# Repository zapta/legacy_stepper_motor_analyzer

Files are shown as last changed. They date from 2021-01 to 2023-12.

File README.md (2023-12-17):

# Legacy Stepper Motor Analyzer

<span style="color:red"><b>
NOTE: This is the legacy STM32 based design which was  replaced by the single board, Raspberry Pi Pico design at https://github.com/zapta/simple_stepper_motor_analyzer.</b></span>

&nbsp;

https://github.com/zapta/legacy_stepper_motor_analyzer

&nbsp;

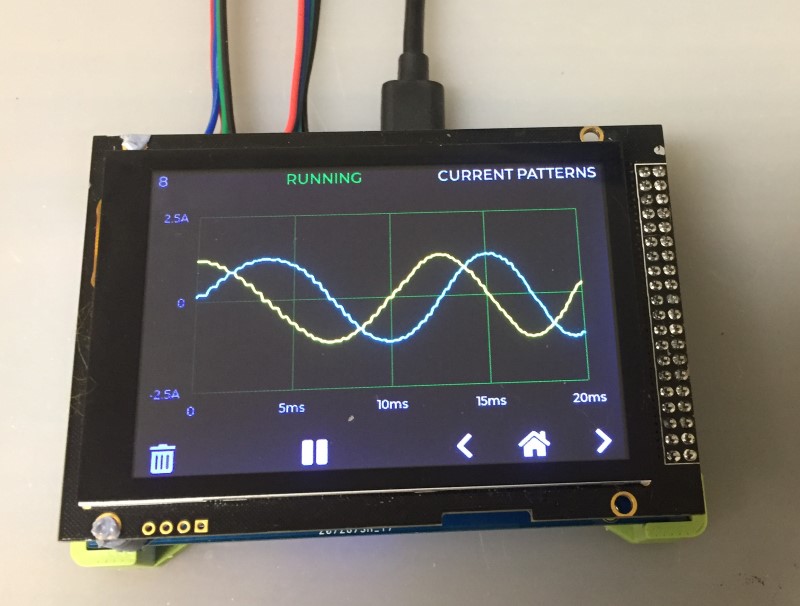
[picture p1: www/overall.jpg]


&nbsp;

## Demonstration

Michael from the Teaching Tech youtube channel made [a great video explaining how stepper motors work](https://youtu.be/4iII25DGIdA) and used the Simple Stepper Motor Analyzer for some of the demonstrations. 

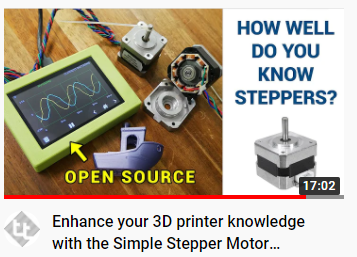
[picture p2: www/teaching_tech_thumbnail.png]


&nbsp;

## Highlights
* Low cost and minimalist DYI hardware design.
* Standalone. Doesn't require a computer to operate.
* Analyzes the stepper motor signals in the actual system (e.g. a 3D printer).
* Galvanically isolated current sensors. Does not interfere with the operating equipment, even when its turned off.
* Easy to connect using a pair 4 wire pass through connectors.
* Intuitive user interface with color display and a capacitive touch.
* Microstepping resolution of 1% of a full step.
* Provides momentary readings, signal patterns, and statistical measurements.
* Hardware and software are open sourced with a generous license.
* Based on free tools (Kicad, platformio, LVGL, STM32Duino).
* Can be easily customized (new featured, cost reduction, data link to a computer, etc).
* Powered 5VDC, 200ma via a USB-C connector.

## Overview
Diagnosing the operation of stepper motor in 3D printers and CNC machines used to require stepper motor analyzers that costs thousands of dollar. Not anymore! The Simple Stepper Analyzer ('Analyzer' in short) brings these capabilities to every maker for a tiny fraction of the price and with a minimalist DIY electronic design that leaves the heavy lifting to the firmware.

The Analyzer is self contained, has two 4-wires pass-through connectors connecting the stepper motor, is powered from a common 5V charger with a micro USB cable, provides a simple to use graphical user interface with a 3.5" color touch screen, and provides a plethora of stepper motor measurements.

The Analyzer is provided to the community as a public domain reference design that can be built and used as is, or be customized with additional features or for a lower cost as desired. The hardware and firmware come with a liberal open source license (CC0) that allows commercial usages and doesn't require code source code sharing.

---
## Disclaimer
THE DESIGN IS PROVIDED "AS IS", WITHOUT WARRANTY OF ANY KIND, EXPRESS OR IMPLIED, INCLUDING BUT NOT LIMITED TO THE WARRANTIES OF MERCHANTABILITY, FITNESS FOR A PARTICULAR PURPOSE AND NONINFRINGEMENT. IN NO EVENT SHALL THE AUTHORS OR COPYRIGHT HOLDERS BE LIABLE FOR ANY CLAIM, DAMAGES OR OTHER LIABILITY, WHETHER IN AN ACTION OF CONTRACT, TORT OR OTHERWISE, ARISING FROM, OUT OF OR IN CONNECTION WITH THE DESIGN OR THE USE OR OTHER DEALINGS IN THE DESIGN.

---

## Alternative construction option (enclosed case)
**NOTE:** This pages outlines the open base construction options which is easier and straight forward. For a more involved and potentially more satisfying construction option, which is also featured in the Teaching Tech youtube video, see https://github.com/zapta/legacy_stepper_motor_analyzer/blob/master/case_option.md

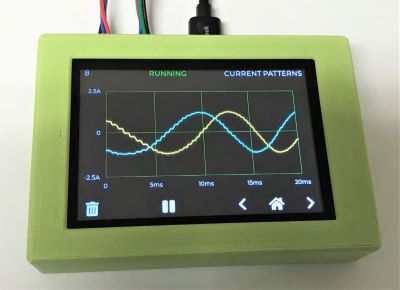
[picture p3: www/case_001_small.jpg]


---
## How does it work?
The principle of operation is very simple, and so is the hardware design. The stepper motor is connected via 4 wire pass-though connectors that allow the Analyzer to monitor the current through the stepper's coils. The Analyzer's user low impedance current sensors that are galvanically isolated such does not interfere with the operation of the 3D printer or other equipment it monitors. The Analyzer measures the coils currents 100k times a second and uses firmware that analyzes the data, extracts the desired measurements, and present them on the screen. For example, this is how an analysis of the distribution of distance by speed distribution looks like:

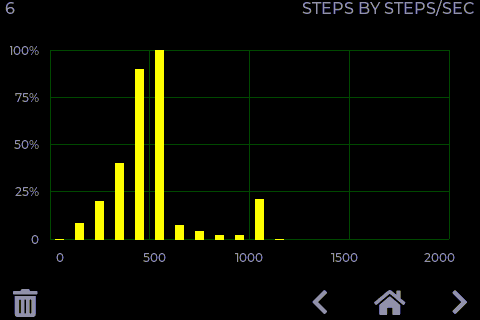
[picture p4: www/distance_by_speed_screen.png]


---
## Operation is simple and intuitive

1. Turn off power to the equipment (e.g. 3D printer).
2. Disconnect the 4 wires of the stepper motor and connect them through the Analyzer two pass through connectors.
3. Power the analyzer using a 5V charger and a micro USB cable.
4. Turn on the equipment and get the stepper going.
5. Use the Analyzer's screen to view the measurements you want.

**NOTE:** The two pass-through connectors of the Analyzer are symmetric and  each can act as an input or output. 

**CAUTION:** Always connect and disconnect stepper motors when their controller is not energized, to reduce the risk of damage to the controller due to high voltage spikes. The analyser itself is not subject to that risk since its uses galvanically isolated current sensors.

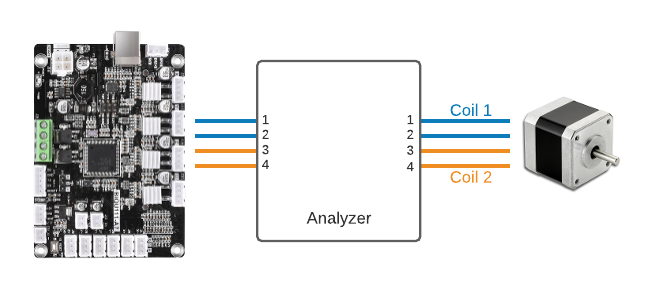
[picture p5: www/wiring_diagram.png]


**NOTE:** The only requirement for proper wiring is that the two wires of one coil should go through pins pair 1,2 and the two wires of the other coil should go through pin pair 3,4. The Analyzer doesn't care about the +/- polarity of the wires in each pair, nor does it care which of the two pass-through connectors is on the controller side and which one is on the stepper side.

**TRIVIA:**: The pin out and the connector type of the Analyzer follows the Duet3D conventions, except that is uses right angle connector to save space.

---
## The Home Page
The Home page is first page shown when the Analyzer is powered on. It provides summary information as well as access to the Settings page.

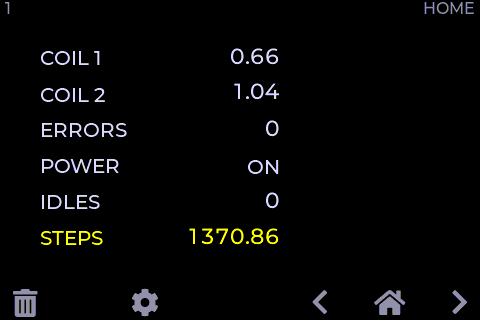
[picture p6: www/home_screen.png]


&nbsp;

#### Page Data

Field | Description
:------------ | :-------------
 COIL&nbsp;1 | Momentary coil 1 current in Amps.
 COIL&nbsp;2 | Momentary coil 2 current in Amps.
 ERRORS | The number of phase errors detected so far. Phase errors happens when the current patterns are so distorted that a forward/backward movement cannot be determined.
 POWER | Indicates if the stepper motor is currently energized. This is determined by the sum of currents in they two coils.
 IDLES | The number of times that stepper motor change status from energized to non energized.
 STEPS | The distance the stepper moved so far. Each full step forward increments this value by one and each full step backward decrements it by one. When the stepper motor is energized, the display also shows fractional steps in resolution of 1/100th of a full step.

HINT: The fractional step value cannot be reset because it is derived from the momentary currents in the two coils. Only the stepper motor driver can reset the fraction by positioning the stepper motor on an exact full step.

HINT: To swap forward/backward directions of the Analyzer use the Settings page. This does not affect the stepper motor itself.

&nbsp;
#### Page Actions

Action | Description
:------------: | :-------------
 | Clear all data.
 | Open the Settings page.

&nbsp;

---

## The Settings Page

This is a special page that is accessible from the Home page and allows to calibrate the Analyzer. The settings are stored in a non volatile memory and are preserved when the Analyzer is turned off.

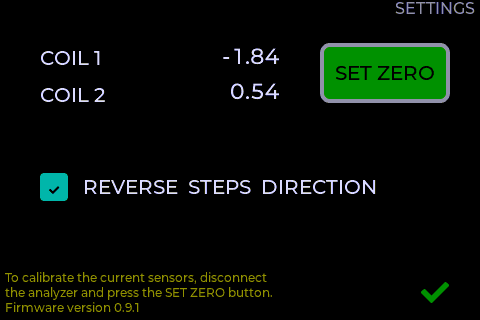
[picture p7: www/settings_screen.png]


&nbsp;
#### Page Data

Data | Description
:------------: | :-------------
COIL&nbsp;1 | The momentary current of stepper coil 1 in Amp units. Should be zero, or very close to zero, when the stepper motor is disconnected.
COIL&nbsp;2 | The momentary current of stepper coil 2 in Amp units. Should be zero, or very close to zero, when the stepper motor is disconnected.

&nbsp;
#### Page Actions

Action | Description
:------------: | :-------------
SET ZERO | Used to calibrate the zero reading of the current sensors. To do so, Disconnect the stepper motor and press this button.
REVERSE STEPS DIRECTION | Changes the forward/backward step directions of the Analyzer. Does not affect the stepper motor itself. Having the correct direction is important for measurements such as the Retraction analysis.
 | Press exist the Settings page.

&nbsp;

---

## The Speed Dial Page

This page measure the stepper speed in units of full steps per second. 

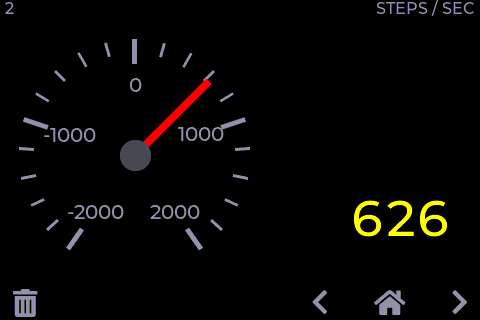
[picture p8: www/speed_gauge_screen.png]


&nbsp;
#### Page Data

Data | Description
:------------ | :-------------
Speed&nbsp;Dial | The speed dial shows the momentary stepper speed in full steps per second units. Forward speed is on the right side and backward speed is on the left.
Speed&nbsp;Value | This field shows the speed in a numeric form. IT is updated less frequently than the dial to allow easy reading.

&nbsp;
**HINT:** The Settings page allows to swap the forward/backward directions.

&nbsp;
#### Page Actions

Action | Description
:------------: | :-------------
 | Clears all data.
Tap the dial |Toggles the dial's speed range.

&nbsp;

---

## The Distance Graph Page

This page shows scrolling graph with the total number of full steps vs. time.

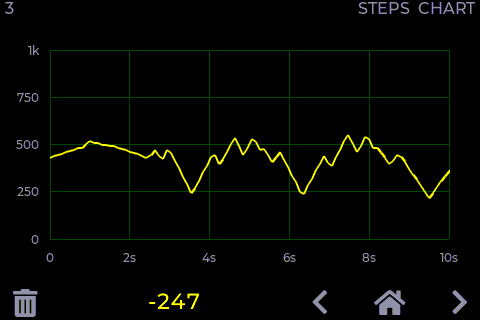
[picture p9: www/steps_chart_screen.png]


&nbsp;

#### Page Data

Data | Description
:------------ | :-------------
Distance&nbsp;Graph | This graph shows how the distance, in units of full steps, changes over time.
Distance&nbsp;value | The numeric value of the distance in full steps.  This fields is identical to the STEPS field in the Home page.

&nbsp;

#### Page Actions

Action | Description
:------------: | :-------------
 | Clears all data.
Tap the graph | Toggles the range of the vertical axis.

&nbsp;

---

#### The Retraction Graph Page

This page is useful to analyze the retraction in of 3D printer extruder.

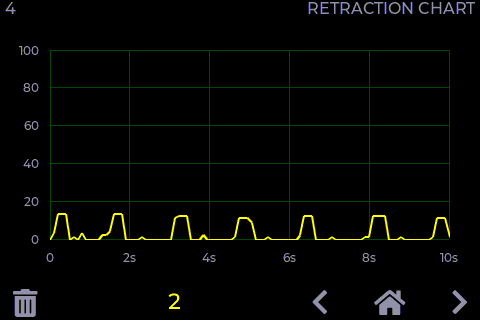
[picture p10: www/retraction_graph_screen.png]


&nbsp;
**TRIVIA:** The graph above was taken while testing a direct extruder printer with [Thing #909901](https://www.thingiverse.com/thing:909901).
&nbsp;
#### Page Data

Data | Description
:------------ | :-------------
Retraction&nbsp;Graph | This graphs tracks the retraction of 3D extruder full step units.  Retraction is defined as the filament length that was inside the extruder and is now retracted outside of the extruder. 
Retraction value |  This field shows the current retraction level in a numeric form.

&nbsp;
#### Page Actions

Action | Description
:------------: | :-------------
 | Clear all data.
Tap the graph | Changes the range of the vertical axis.

&nbsp;

---

## The Time by Speed Page

This page shows an histogram with the distributing of time by stepper speed. That is how much time was spent in each speed range. The values are normalized such that the longest bar is always at 100%.

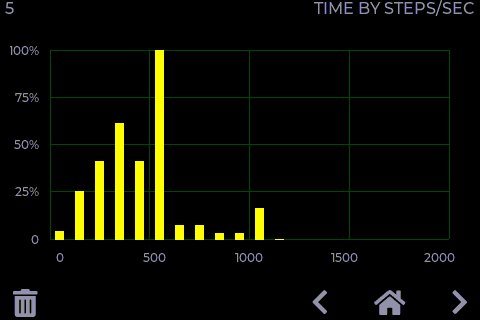
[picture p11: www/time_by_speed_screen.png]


&nbsp;
#### Page Data

Data | Description
:------------ | :-------------
Time&nbsp;Histogram | The horizontal axis indicates speed in full steps per second units. The height of each bar indicate the time of all steps in that speed range, with the length of the longest bar normalized to 100%.

&nbsp;
#### Page Actions

Action | Description
:------------: | :-------------
 | Clear all data.

&nbsp;

---

## The Distance by Speed Page

This page shows an histogram with the the distribution of distance by stepper speed.



&nbsp;
#### Page Data

Data | Description
:------------ | :-------------
Distance&nbsp;Histogram |  The horizontal axis indicates speed in full steps per second units. The height of each bar indicate the distance or number of steps in that speed range, with the length of the longest bar normalized to 100%.

&nbsp;
#### Page Actions

Action | Description
:------------: | :-------------
 | Clear all data.

&nbsp;

---

## The Current by Speed Page

This page measures the ability of the stepper motor's controller to maintain peak current at high speeds.

The screenshot below shows a healthy system where the peak current is virtually flat across the speed range.

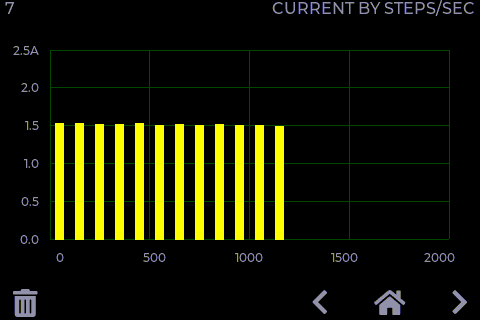
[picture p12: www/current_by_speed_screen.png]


The screenshot below shows a system that is not capable to maintain peak current and starves the stepper motor at high speeds, resulting in poor torque and possible skipped steps.

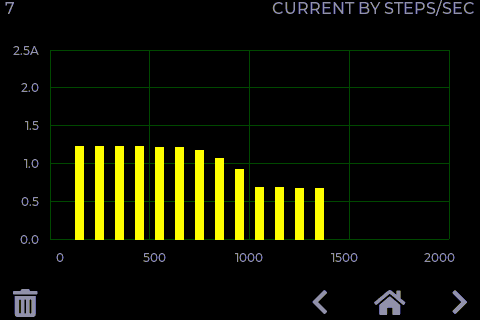
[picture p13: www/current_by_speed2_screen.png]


&nbsp;
#### Page Data

Data | Description
:------------ | :-------------
Peak&nbsp;Current&nbsp;Histogram | The horizontal axis indicates speed in full steps per second units. The height of each bar indicates the average peak current in Amps of  steps that speed range. 

&nbsp;
#### Page Actions

Action | Description
:------------: | :-------------
 | Clear all data.

&nbsp;

---

## Coil Current Patterns Page

This page shows the current patterns in the two stepper coils.

The screenshot below shows a healthy system where the signals are nice and clean and reaches the target peak current.

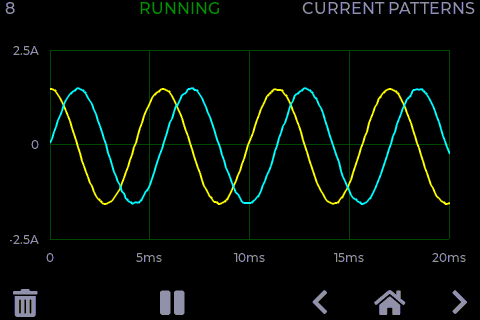
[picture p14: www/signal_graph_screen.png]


&nbsp;

The screenshot below is from a poor system where high speed results in distorted and insufficient current, resulting in loss of torque and a potential for skipped steps.

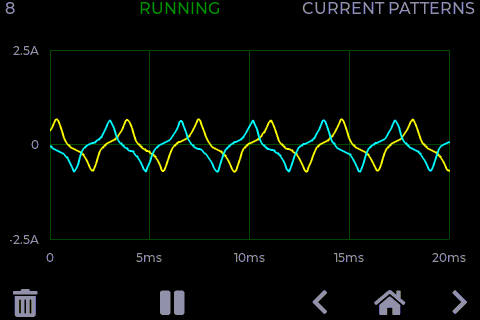
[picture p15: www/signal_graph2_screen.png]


&nbsp;

**GENERAL INFORMATION:** Each cycle of the stepper current pattern represent 4 full steps. The centers of those steps are at on the four vertical dotted lines where the currents of the two coils are identical, in the same or in  opposite polarities. The transitions between the steps are on the 4 vertical solid lines where one of the coils is at zero current. This cycle of 4 full steps is sometimes referred to as a single 'electric rotation'. The analyzer computes the exact phase on this cycle using the standard trigonometric function atan2(current1, current2) which can also be calculated manually from the current readings in the Home page.

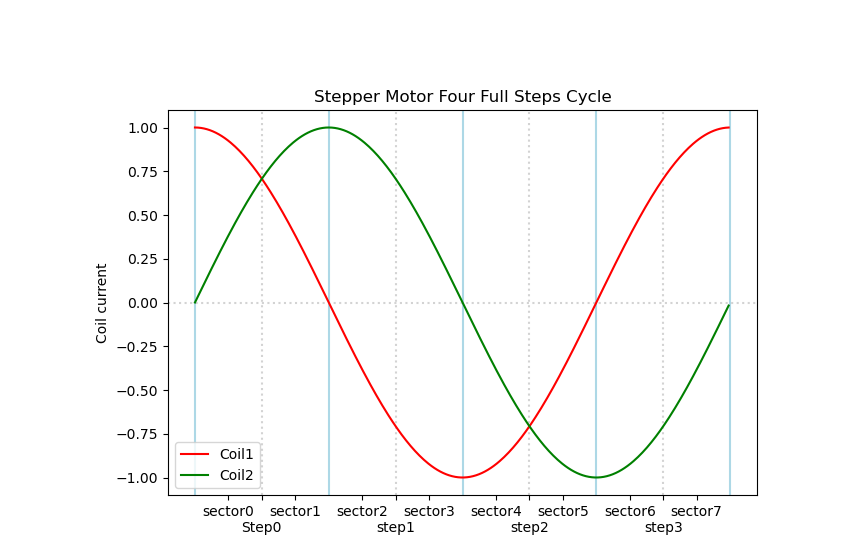
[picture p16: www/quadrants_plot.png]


&nbsp;

#### Page Data

Data | Description
:------------ | :-------------
Current&nbsp;graph | The horizontal axis indicates time in milliseconds. The vertical axis indicate coil current level in Amps. The two graphs show the current patterns of the respective stepper coils.

**NOTE:** The graph is updated only when sufficient stepper motor movement is detected.

&nbsp;
#### Page Actions

Action | Description
:------------: | :-------------
 | Clear all data.
 | When running, pauses the display updates.
 | When paused, resume the display updates.
Tap the graph | This toggles the range of the horizontal axis.

&nbsp;

---

## Coil Current Phase Page

This page draws the current patterns of the two coils as a [Lissajous curve](https://en.wikipedia.org/wiki/Lissajous_curve) which allows to examine visually distortions such as non sinusoidal current, phase distortion, and reduced amplitude.

In an ideal system, the graph is a perfect smooth circle, that doesn't change its size when the stepper's speed changes. Patterns that significantly diverge from that indicates a sub optimal configuration and operation.

Following picture shows a pattern from a well functioning system. The graph is round, reasonable smooth, and has sufficient size which indicates good current drive. 

The horizontal axis indicates the coil 1 current and the vertical axis indicates coil 2 current. In this example, both span nicely between -2A to +2A.

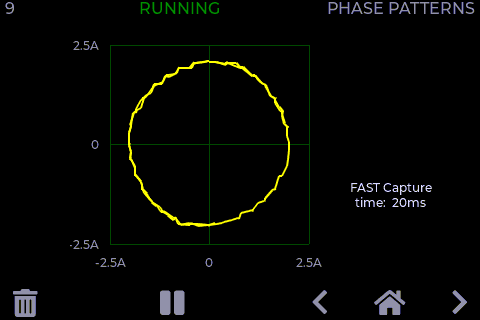
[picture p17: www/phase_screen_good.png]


&nbsp;

The screenshot below is from a poor system where high speed results in distorted and insufficient current, resulting in loss of torque and a potential for skipped steps. The pattern is far from a clean circle and the shape has reduced size.

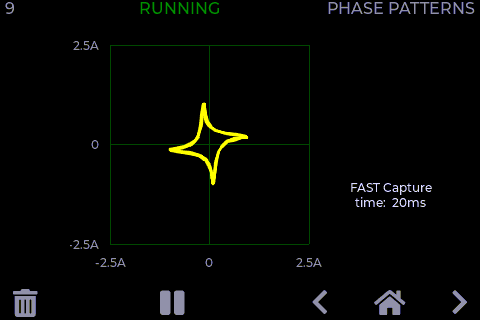
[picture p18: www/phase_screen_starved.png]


&nbsp;

The screenshot below shows a sub optimal operation where a a speed increase of the stepper results in small (less current and torque) and even more distorted curve.

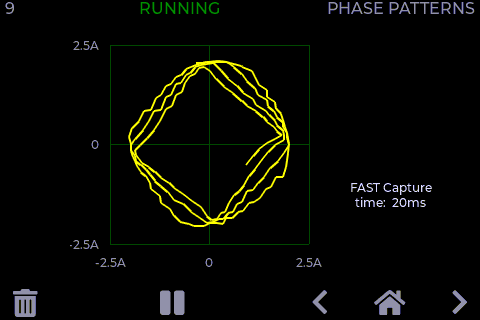
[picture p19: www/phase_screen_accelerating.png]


&nbsp;

The screenshot below shows a well functioning system. The smaller size of the circle compare to the example above indicates that it operates on lower current.

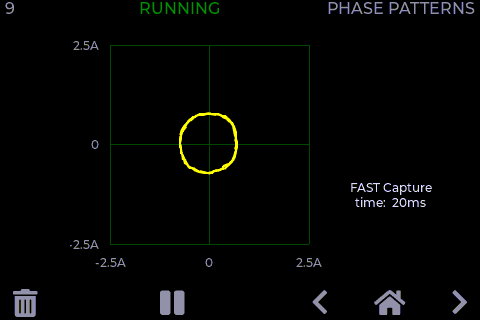
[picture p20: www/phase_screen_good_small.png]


&nbsp;

The screenshot below show an operation of a stepper in full steps mode. The dimension of the pattern indicate good current feed, and the square  shape is the best a full step driver can deliver.

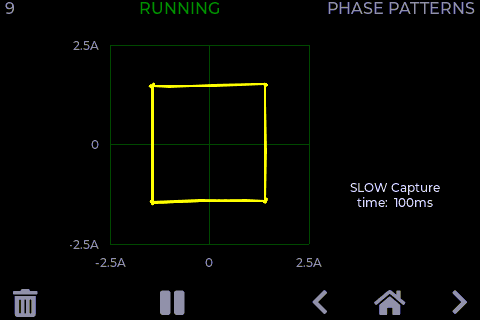
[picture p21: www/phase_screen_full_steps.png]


&nbsp;

The screenshot below show an operation of a stepper in half steps mode. The dimension of the pattern indicate good current feed, and the shape is somewhere between the square shape of full step mode and the round shape of micro stepping interpolation mode.

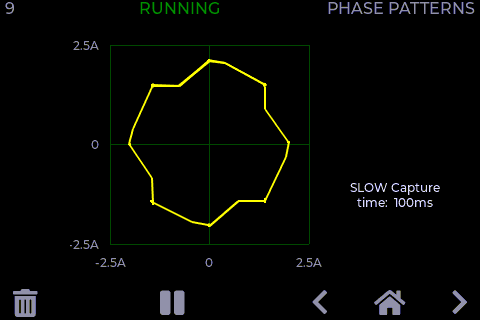
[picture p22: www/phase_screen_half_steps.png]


&nbsp;

#### Page Data

Data | Description
:------------ | :-------------
Lissajous&nbsp;curve | A Lissajous curve drawn from the current pattern of coil 1 (x) and coil2(y). 
Capture speed | Shows the signal capture time. Fast mode works better with fast moving steppers and slow mode works with slow moving steppers. Tap the graph to toggle.

**NOTES** 
* The graph is updated only when sufficient stepper motor movement is detected.
* To view the current pattern that resulted in the current phase pattern, use the navigation button to switch the current patters page, and vice versa.

&nbsp;
#### Page Actions

Action | Description
:------------: | :-------------
 | Clear all data.
 | When running, pauses the display updates.
 | When paused, resume the display updates.
Tap the graph | This toggles the capture time between fast and slow speeds.

&nbsp;

---

## Reference Design Specification

Item | Specification
:------------ | :------------- 
Power consumption | 5V, 175ma.
Power connector | micro USB
MCU | 32bit ARM STM32F401CE @ 84Mhz.
Flashing | USB/DFU or SWD/Stlink V2.
Data link | USB/Serial link available but not used.
Current measurement | +/-2.5A per coil. +/-5A sensors available.
Dimensions | 97 x 66 mm
TFT Resolution | 480 x 320, Color. Landscape mode.
Touch screen | Capacitive
Sensor isolation | See ACS70331 data sheet
Sampling rate | 100Khz per channel.
Sampling resolution | 12bits
Current accuracy | estimated at +/- 1%
Max speed | Software dependent. Currently 2K full steps/sec.
Step resolution | 1/100th of a full step.
Partial steps measurement | Software dependent. Not implemented.
Settings storage | On board EEPROM chip.
GUI framework | LVGL library. R3G3B2 color depth.
Programming language | C++
Programming IDE | Platform.io. Arduino/STM32.
Cad package | Kicad.

&nbsp;

---

## I want to build me one

The electronic schematic, PCB layout, gerber files, and the firmware source files and released binary are all available on this github repository.

[Schematic](./www/stepper_analyzer-sch.pdf)

[BOM](https://github.com/zapta/legacy_stepper_motor_analyzer/blob/master/kicad/BOM.csv)

<span style="color:red"><b>
ERRATA: The current PCB version leaves the RD input on the TFT (pin 26) floating which can  interfere with the operation of the display. One workaround is to patch the board with a resistor to pull the input to +3.3v (but not to +5V!!!). See the errata in the latest schematic for more details.</b></span>

&nbsp;

**Instructions:** Build the PCB, use DFU or SWD protocols to program the released binary into the Blackpill, plugin the TFT screen, power and use. See instructions below on how to flash the firmware release you can find on this github repository.

**NOTE:** These instructions are for the simpler  version which uses an open frame base. For ordering parts and building the enclosed version see https://github.com/zapta/legacy_stepper_motor_analyzer/blob/master/case_option.md .

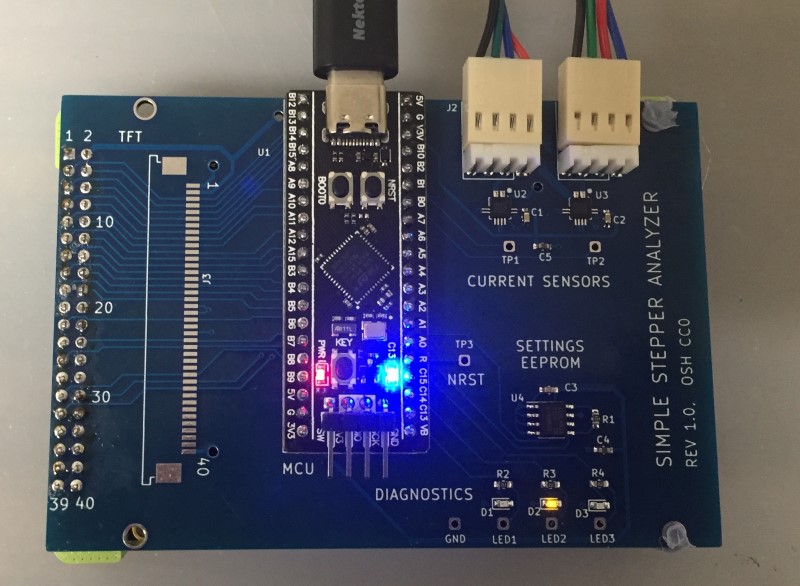
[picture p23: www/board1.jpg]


&nbsp;

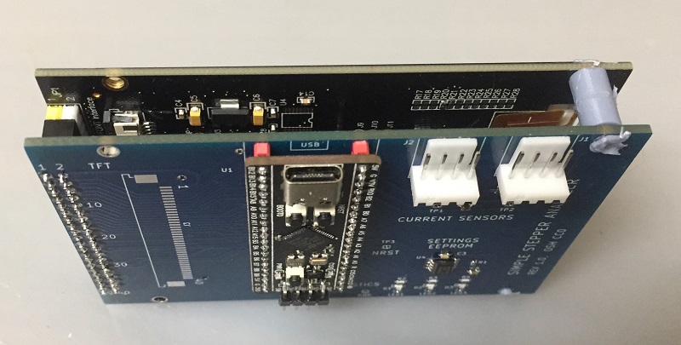
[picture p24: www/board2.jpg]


## Flashing a new firmware
Flashing the Analyzer with firmware can be done in a few ways. For software developers we recommend using StLink V2 and SWD which are well supported by the platformio IDE and enable debugging ans single stepping. A simpler approach that is recommended for end users is to use the builtin DFU protocol of the Analyzer's STM32 processor such as the one we use here. Adafruit has a [good description of the process](https://learn.adafruit.com/adafruit-stm32f405-feather-express/dfu-bootloader-details). The only difference that to enable the DFU bootloader mode connect the analyzer to the computer while its BOOT0 on button on the back is pressed.

**ONLINE LOADER:** We also had good results with Google Chrome browser and this online loader https://devanlai.github.io/webdfu/dfu-util/ . The Analyzer should appear as STM32 BOOTLOADER and should be programmed with the configuration Internal Flash 0x08000000.

## How to modify the firmware?
The source code of the Analyzer is available on this github repository. It is a STM32 C++ Platformio project that uses the Arduino framework. The user interface is based on the LVGL library and the project includes its own port to support TFT/Touch used.  Knowledge of C++ and Platformio is required and is outside the scope of this document.

## Mechanical
We provide here a [3D model of a simple open frame carrier](./3d/base.stl). This design does not requires attaching the analyzer and the TFT board with screws or spacers and guarantees proper separation on the loose end. If you have an interesting design which you would like to share, please post in a model sharing site such as cults3d, thingiverse or grabcad and we will link it here.

This open frame base does not require any spacers between the two boards and was designed 
to prevent them from unintentionally touching each other.

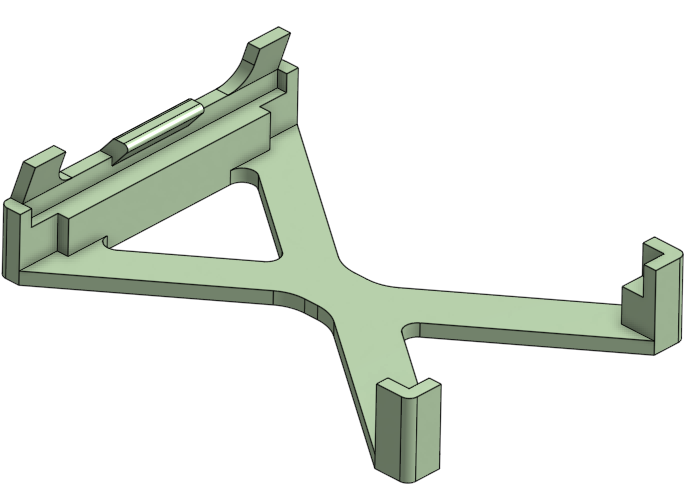
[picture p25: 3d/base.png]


## Ideas for improvements
The Analyzer is provided as a fully functional reference design and changes and the developers encourage improvement/modifications of the hardware and/or firmware are encouraged. This can include new features, new measurements and pages, extending the design to support 2 or 3 steppers at once to track the x/y/z of a 3D printer, reducing the hardware cost using less expensive screen TFT, or even eliminating the screen altogether and using the Analyzer as a dongle tethered to a computer via the existing USB/Serial link.

&nbsp;

---

## FAQ

#### Q: Why not a SPI based TFT?

A: We could not achieve fast enough display refresh rate with SPI so switched to 16 bit parallel data transfers.

#### Q: Can a cheaper TFT/touch be used?
A: Yes, but it may require firmware changes.

#### Q: Can the TFT screen be eliminated?
A: Yes. The Analyzer has a USB/Serial output can a small Analyzer dongle can communicate with a computer program. This will require firmware changes.
 
#### Q: Can I connect the Analyzer to the TFT using a FFC cable?

A: Yes. The PCB was designed for both 0.1" header and 40 pins 1.0mm FFC cable connections.  You will need a short (e.g. 60mm or less) type B ('reversed') FFC cable. Cables longer than let's say 100mm may introduce noises the will interfere with the operation of the display. 

#### Q: Can you add feature X or customization Y?

A: Most likely not. The reference design is provided for the community to change and mix.

#### Q: I want to commercialize or crowd source it, can you help me?

A: Most likely not. The reference design is open source and you will need to find others to help you.

#### Q: Where do I file a bug?

A: Use the github repository.

#### Q: Is it ok to connect/disconnect power to the Analyzer while my 3D printer prints?

A: Of course. The Analyzer is isolated from the stepper wires and should not interfere with the operation of the printer.

#### Q: The Analyzer uses LVGL lib, what is the license of that library?

A: At the time of writing this, the LVGL license is available here https://github.com/lvgl/lvgl/blob/master/LICENCE.txt.  The Analyzer's developers are not affiliated with LVGL.

#### Q: Is the LVGL library included in the Analyzer's repository?

A: It's not needed. LVGL is supported by platform.io so the Analyzer's project is set for platform.io to fetch LVGL automatically.

#### Q: Can I use a STM32F401CE MCU with a 8Mhz crystal.

A: The provided firmware assumes a 25Mhz crystal. For a 8Mhz crystal you will need to change the firmware.

#### Q: I can't find a STM32F401CE/25Mhz blackpill but I can find an STM32F411CE/25Mhz, will this work?

A: Most like it will work with the provided firmware as is (and with no performance benefits), but we do not guarantee it. We may switch the official reference design to the STMF411CE/25Mhz if the STM32F401CE/25Mhz, which is less expensive, will not be available.

#### Q: Can I use a blackpill with different pinout than WeAct ?

A: No, unless if you are willing to change the PCB.

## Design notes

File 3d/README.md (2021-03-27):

3D Models for printing. 

Base is an open frame design that uses a standard 0.1" headers to connect
the display and the Analyzer boards.

Case is a closed design that is more appealing but also more difficult
to build. It uses a type B (reversed) 40 wires 0.1" flex cable to connect
the two boards and M2.5 heat inserts to attache the front and the back 
of the case.

Both designs use the same PCB design and use 16 bit parallel data path to the 
display, but with different 40 wires connectors.

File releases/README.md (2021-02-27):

## Simple Stepper Analyzer Releases
This directory contains the official releases of the Simple Stepper Analyzer which are provided as .bin files that can be flashed to the analyzer.

The binaries can be programmed via the USB connector using the builtin STM32 DFU bootloader. The invoke the DFU mode, connect the analyzer to a computer via a USB cable while holding the BOOT0 button at the back of the analyzer.

Unless specified otherwise, the binaries where compiled for a STM32F401CE MCU
(which typically can also run on a STM32F411CE MCU).

&nbsp;

Binary file | version | Comments
:------------ | :------------- | :---------
[firmware-2021-02-26.bin](./firmware-2021-02-26.bin) |  0.9.13 |  Increased buttons' click area.
[firmware-2021-02-15.bin](./firmware-2021-02-15.bin) |  0.9.12 |  Added phase analysis screen.
[firmware-2021-02-01.bin](./firmware-2021-02-01.bin) |  0.9.11 |  First released version.

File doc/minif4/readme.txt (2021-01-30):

Content from https://github.com/WeActTC/MiniF4-STM32F4x1

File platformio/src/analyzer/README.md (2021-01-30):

The acquisition direction contains the part of the firmware that 
process the ADC samples and extracts the measurements. All that processing
is done by an interrupt routine that process every 1ms 100 pairs of 
ADC samples that are collected in memory by a DMA channel. The pairs of ADC
samples are triggered by a 100khz timer that is set in bye ../hal/tim.cc file.

Before you change any part of the interrupt routine make sure you know
what you are doing.

The file quadrant_plot.png shows how a single stepper motor cycles
is divided into 8 cases and 4 quadrant representing 4 full steps.

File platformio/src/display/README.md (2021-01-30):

This directory contains the port of LVGL to the hardware we use. It includes
an ILI9488 480x320 TFT driver, a capacitive touch screen driver and
the LVGL interfaces to these drivers.

To achieve faster refresh rate we use 16 bits data path to the TFT. These
16 output pins are allocated in PORTA and PORTB and we use lookup table
for a fast update of those pins to output a specific 16 bit value.

To reduce memory consumption we also run LVGL in 8 bit color mode and 
use the lookup tables mentioned above to also do the conversion from
LVGL 8 bit colors to the TFT's 16 bit colors.

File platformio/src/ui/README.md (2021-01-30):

This directory contains the GUI screens. They are switched
by screen-manqager.cpp.

The ui.* files contains simple wrappers and common functionality
for working with LVGL.

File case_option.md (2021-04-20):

# Fully enclosed 3D printed case option

&nbsp;

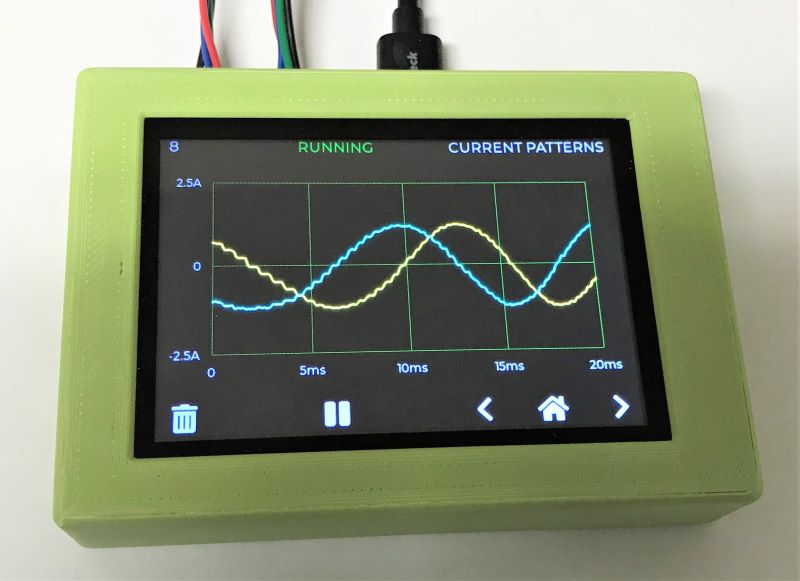
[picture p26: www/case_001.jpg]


&nbsp;

## Summary
This page describes an alternative way to constructs the the Simple Stepper Motor Analyzer that is slightly more involved and arguably more satisfying than the standard option. Instead having the analyzer's board connects to the TFT screen via a 40 pins header and placed on a 3D printed open base, it is attached via a short flex cable (FFC) and is held in a fully enclosed 3D printed case.

## Differences from the the standard open base construction
* This option uses the exact same PCB and electronic components as the standard options.
* Instead of soldering the 2x20 pin 0.1" header on the analyzer's PCB, solder a 40 pin 1.0 FFC surface mount connector.
* Instead of ordering a TFT module with a 40 pin header, order the same TFT module but with the FFC connector option.  (If you already have the TFT module with the 40 pins header option and if you are good with soldering, you can convert it by removing the header and soldering instead a FFC connector).
* Use a short 40 wires (ideal ~30mm, longer such as 60mm should also work), 1.0mm FFC cable to connect the analyzer and TFT boards. You will need a 'type B' or 'reversed' cable type that has the exposed contacts of opposing sides.
* 3D print the parts in the file http://github.com/zapta/simple_stepper_motor_analyzer/blob/master/3d/case.stl
* Set the temperature of your solder iron close to the printing temperature of the case and use it to embed four M2.5 x 3.5mm OD x 3mm length brass threaded inserts.
* Use four M2.5 16mm socket head screw to attach everything together, the four spaces fit between the TFT and the analyzer's PCB.

**NOTE:** The OnShape source file of the case is at 
https://cad.onshape.com/documents/146b8b994145177887407b23/v/f2052a33bf7ac8993e3d7406/e/b6453eca2ba530476c30538a

&nbsp;

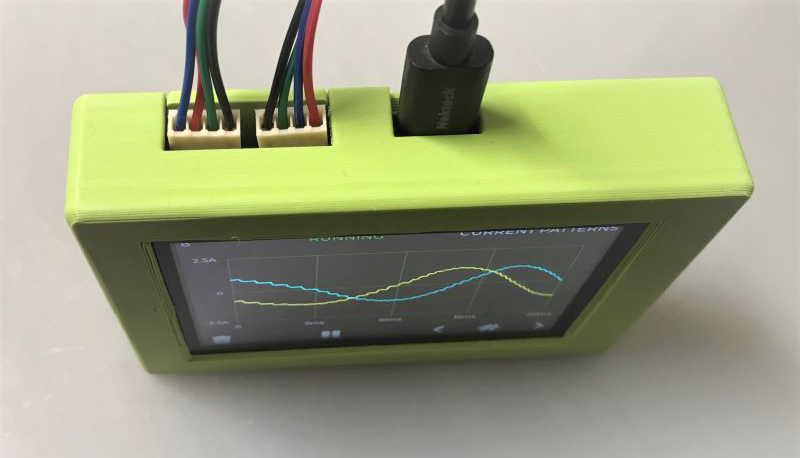
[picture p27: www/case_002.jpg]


&nbsp;

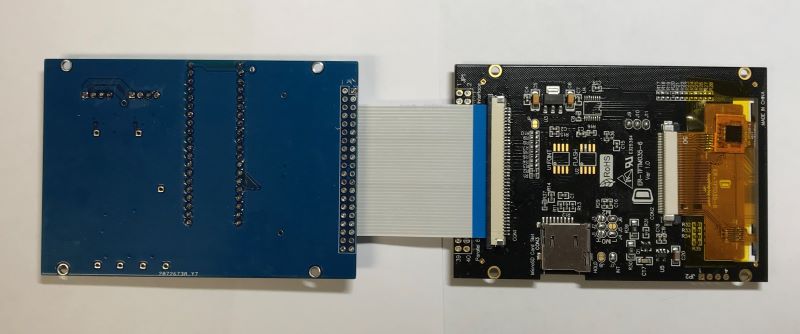
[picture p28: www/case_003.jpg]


&nbsp;

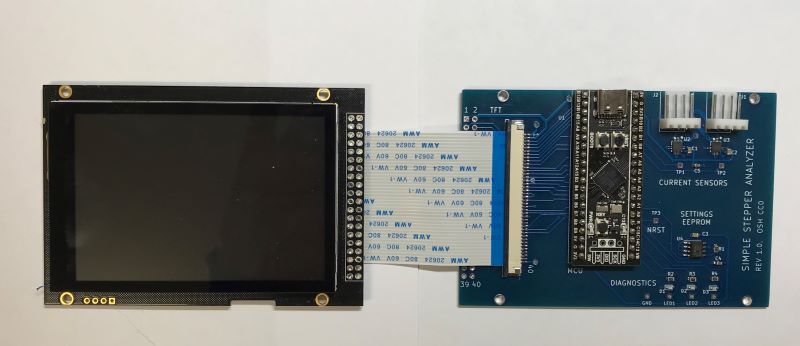
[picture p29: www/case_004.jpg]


&nbsp;

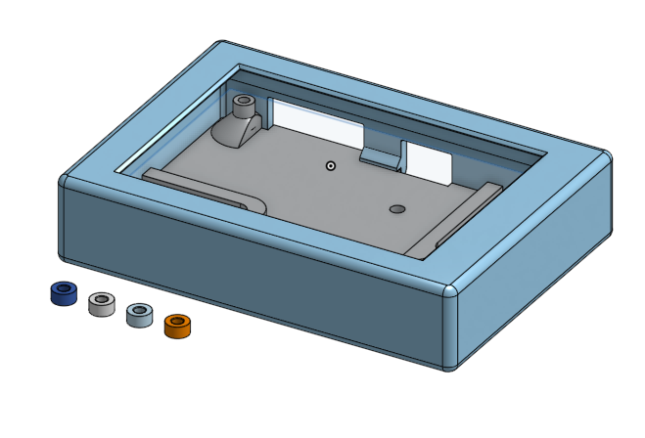
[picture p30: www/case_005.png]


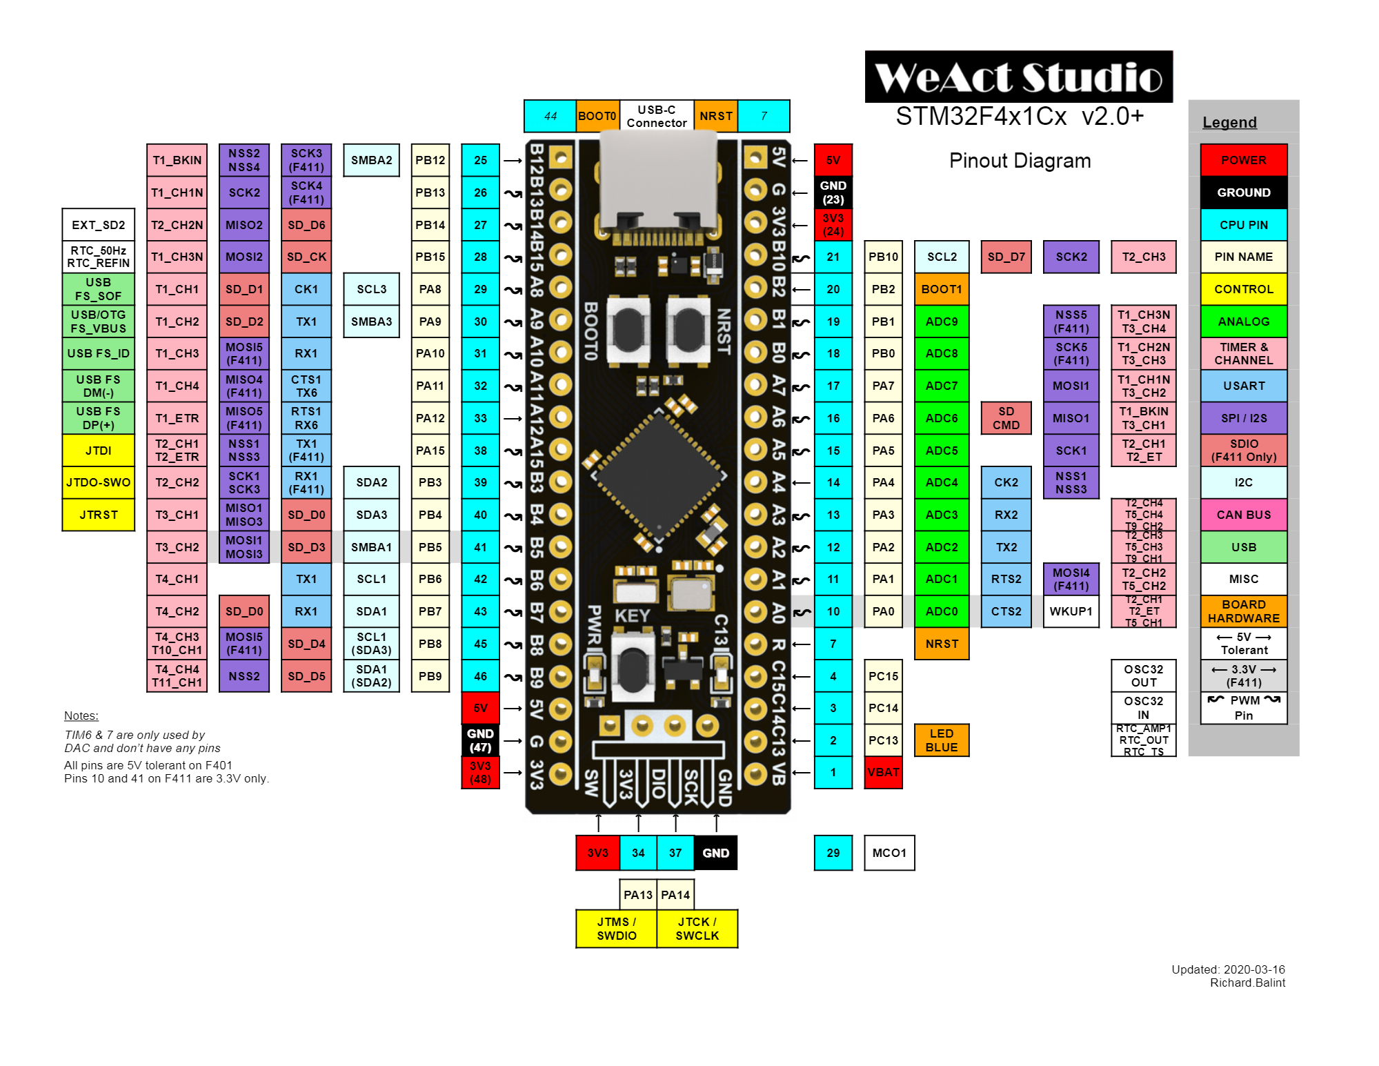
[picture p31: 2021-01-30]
doc/minif4/pinout.png

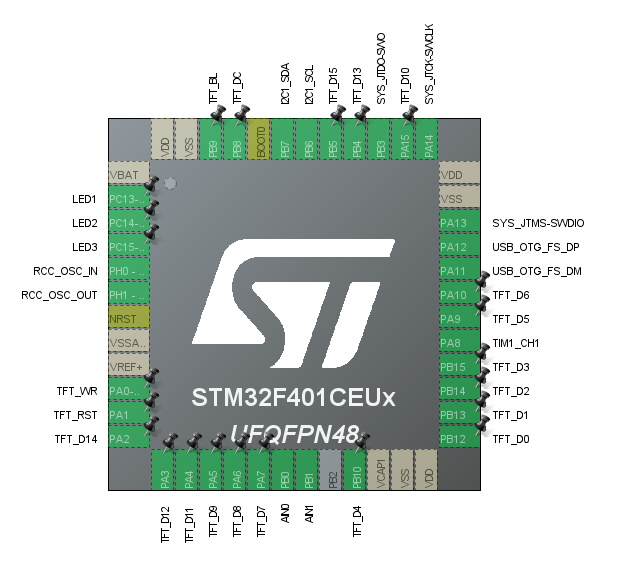
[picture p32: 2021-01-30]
doc/stm32_config/pinout.png

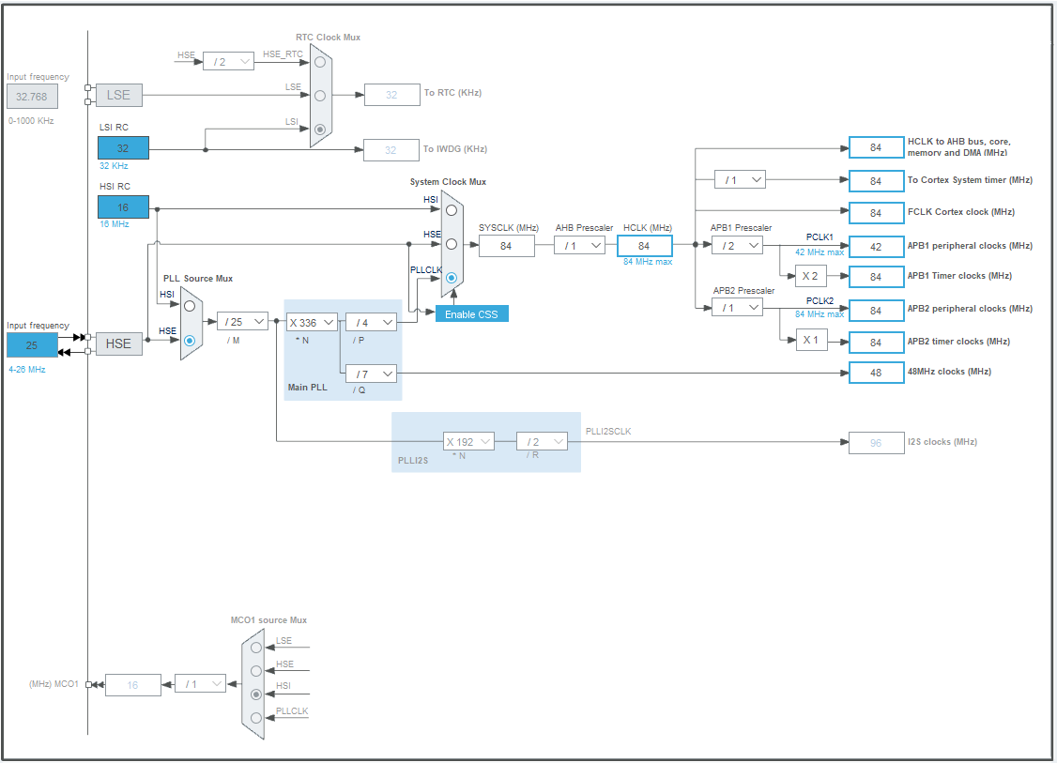
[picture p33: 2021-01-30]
doc/stm32_config/clock.png

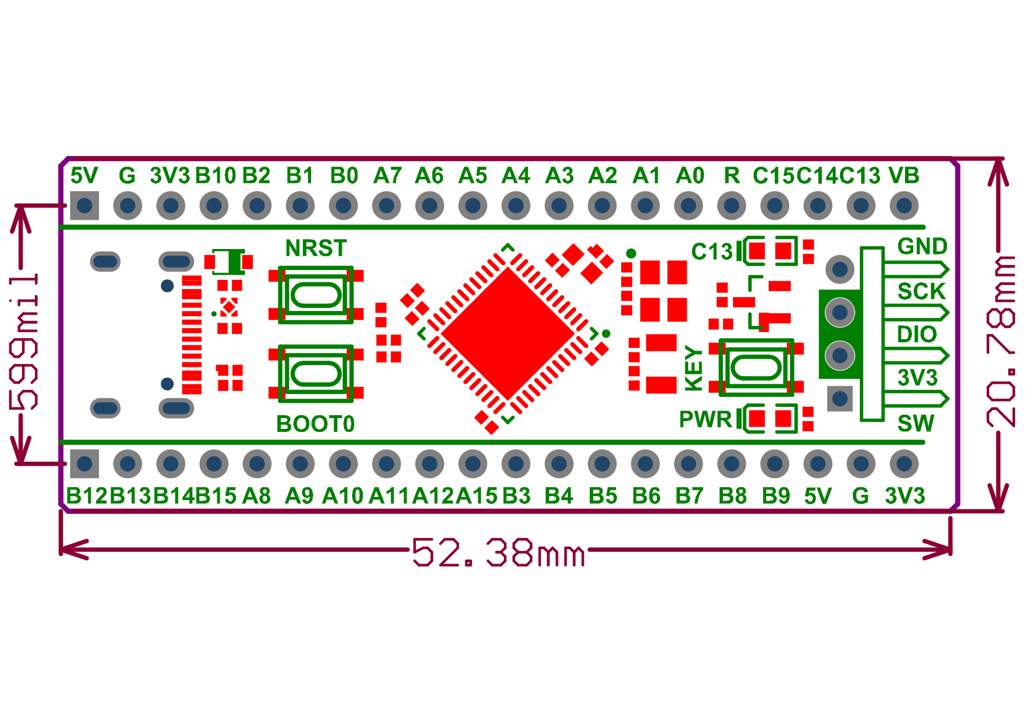
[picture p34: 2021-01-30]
doc/minif4/outline.png

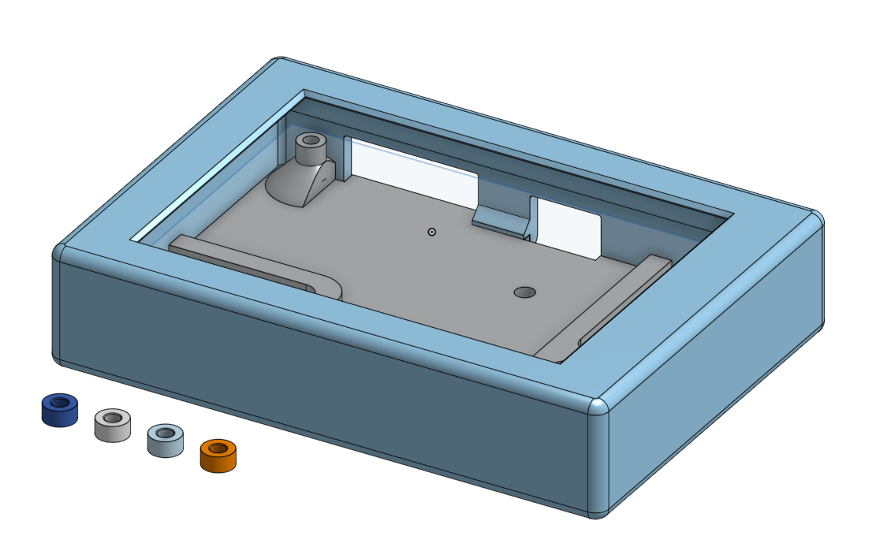
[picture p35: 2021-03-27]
3d/case.png

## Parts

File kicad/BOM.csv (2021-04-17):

Quantity | Ref | Value | Status | Description | Source | Comments
3 | C1, C2, C3 | 100nf | Required | Ceramic capacitor 100nf, at least 10V, SMD 0603 | Digikey 311-1369-1-ND | Generic component, available from other sources.
2 | C4, C5 | 10uf | Requires | Ceramic capacitor 10uf, at least 10V, SMD 0603 | Digikey311-1817-1-ND | Generic component, available from other sources.
1 | R1 | 10k | Required | Chip resistor 10k, SMD 0603 | Digikey 13-AC0603FR-0711KLCT-ND | Generic component, available from other sources.
2 | J1, J2 | 4 pins right angle connector | Required | KF2510 male connector right angle 0.1” pitch pin header | https://www.aliexpress.com/item/4000587555738.html | Generic component, available from other sources.
1 | J4 | 2x20 0.1” female header. | Required | Connector_PinSocket_2.54mm:PinSocket_2x20_P2.54mm_Vertical | https://www.aliexpress.com/item/32747224548.html | Generic component, available from other sources.
1 | U1 | WeAct STM32F4x1CE blackpill module. | Required | WeAct blackpill STM32F401CE 25Mhz or STM32F411CE. Comes with 2x20 pin headers to solder the blackpill to the analyzer’s PCB. | https://www.aliexpress.com/item/1005001456186625.html | Some clones of WeAct modules are available. Make sure to have the same pinout and legit MCU. STM32401CC wouldn’t work, also, make sure it has 25Mhz crystal (vs 8Mhz).
2 | U2, U3 | ACS70331EESATR-2P5B3 | Required | Alegro current sensor, bidirectional, +/-2.5A. | Digikey 620-1889-1-ND
1 | U4 | AT24C02D-SSHM-T | Required | I2C EEPROM 256x8 | Digikey AT24C02D-SSHM-TCT-ND | Clones are available on Aliexpress. We didn’t test them but should work as well.
1 |  | Analyzer PCB Rev 1.0 | Required | Gerber files are available the github repository. 96.7 x 66.4mm two layers. | JLCPCB, Pcbway, your prefer PCB vendor or shop at https://pcbshopper.com/
1 |  | BuyDisplay 3.5” TFT with touch display | Required | ER-TFTM035-6, Pin Header Connection-8080 16-bit Parallel, 5.0V, Capacitive Touch Panel, No font chip. | https://www.buydisplay.com/lcd-3-5-inch-320x480-tft-display-module-optl-touch-screen-w-breakout-board | Make sure to select the exact options listed in the Description column. See example at https://github.com/zapta/simple_stepper_motor_analyzer/blob/master/www/tft_order_options.png
3 | D1, D2, D3 | LED 0603. | Optional, for firmware development only. | LED SMD 0603, colors of your choice. | https://www.aliexpress.com/item/32888575577.html | Generic component, available from other sources.
3 | R2,R3, R4 | 3k3 | Optional, for firmware development only. | Chip resistor 3.3k, SMD 0603 | Digikey YAG3354CT-ND | Generic component, available from other sources.
1 |  | STLINK V2 | Optional, for firmware development only. | Hardware debugger for STM32 MCUs. | Digikey 497-10484-ND | Inexpensive USB dongle clones are available from Aliexpress. We expect them to work but didn’t test them.

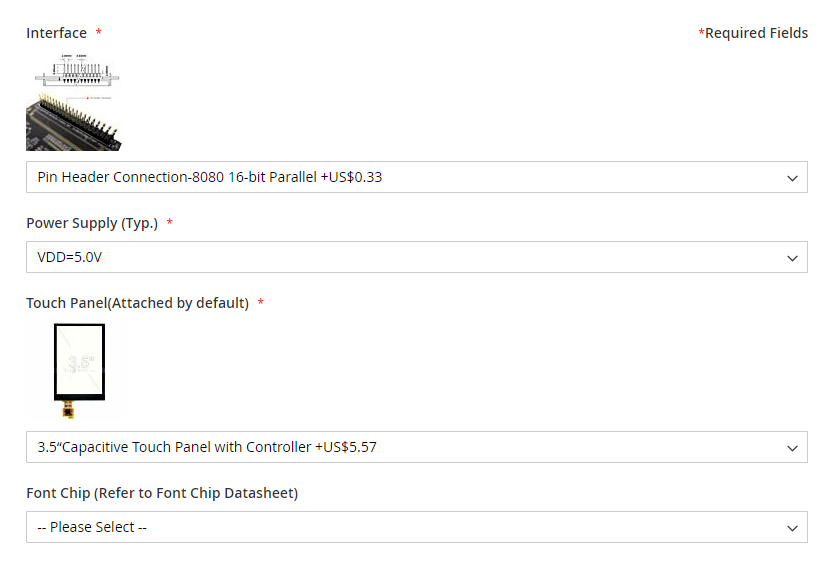
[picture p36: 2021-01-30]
www/tft_order_options.png

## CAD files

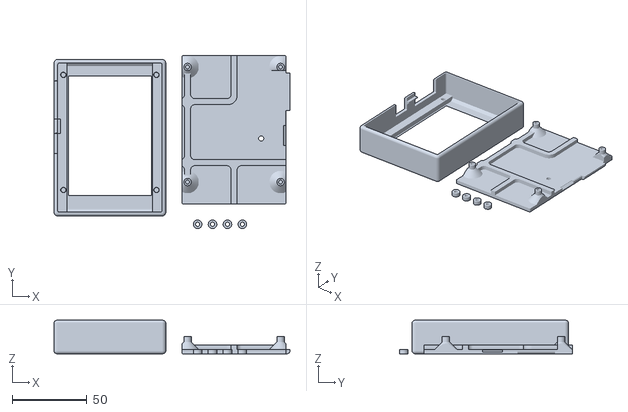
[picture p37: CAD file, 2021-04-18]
3d/case.stl
158.3 x 116.2 x 22.5

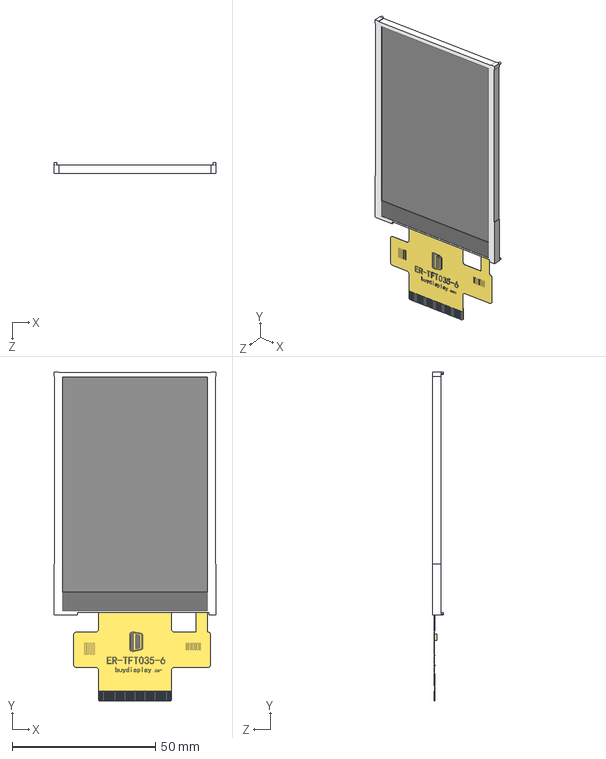
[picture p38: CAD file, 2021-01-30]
doc/ER-TFT035-6.step
56.5 x 115.0 x 3.85 mm

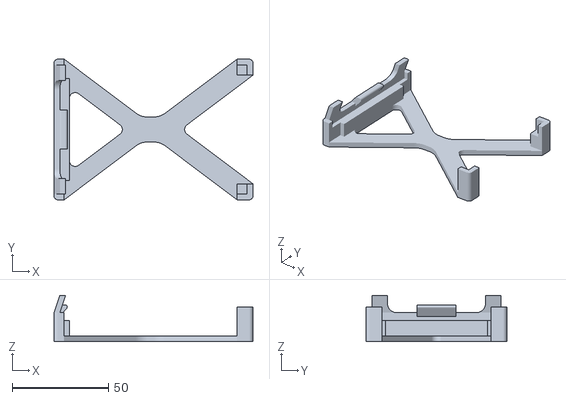
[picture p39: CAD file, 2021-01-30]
3d/base.stl
103.3 x 73.0 x 24.0

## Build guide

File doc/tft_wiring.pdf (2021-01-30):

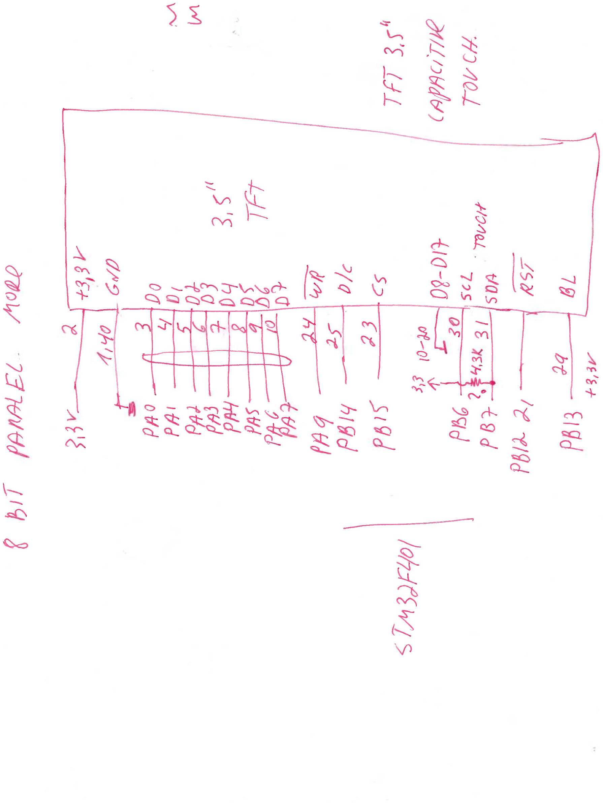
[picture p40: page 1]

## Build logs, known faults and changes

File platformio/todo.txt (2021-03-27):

* Try to eliminate the external EEPROM by storing the settings in internal flash per discussion at https://community.platformio.org/t/how-to-reserve-a-page-of-flash-memory-stm32-arduino/18664

* Consider adding a SD card (SPI connection).

* Make the blackpill's builtin 'key' button available to whatever we want.

* Explore if we can get good refresh rate and user experience with a 320x240 TFT / Resistive touch (cheap) and dual buffering SPI + DMA.

* Can we have a RPI pico base version? Having two cores may allow parallel render/tft-update.

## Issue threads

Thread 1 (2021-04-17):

Great project, maybe an idea for the future

Greg191134, 2021-04-17:
That's a great project (discovered through TeachingTech video) so just an idea that may complement it

If the analyser had a daughter card with a hall effect sensor that you could mount to the rear of the stepper (+magnet on the stepper axis) that would also allow to measure the linearity of the stepper movement which would be really interesting (for instance to evaluate Vertical Fine Artefacts created by steppers on 3D printers)

While the precision may not be sufficient to make a fine analysis, if you make a bench where the stepper axis is connected to a speed multiplier train with 2x80/16 teeth pulleys + belts in series and you measure the movement on the outlet axis (x25 compared to the stepper axis) you can probably get interesting and more accurate results

Cheers

zapta, 2021-04-17:
Greg, your idea is very interesting, and and there are other product configurations that can be derived from this simple concept that is demonstrated by the analyzer design here.  For example, a small board, with sensors to 1, 2 or 3 steppers, and a microcontroller with USB data connector, no LCD, which connects to an app on a computer (the sensors are galvanically isolated so it's safe) that performs the cross motor analysis (e.g. head x,y in a coreXY system). Hardware cost should be minimal.

The design was published with minimal restrictions (CC0, public domain license) to encourage makers and entrepreneurs to pick the idea and provide products to the community.  Did I hear 'Kickstarter' ?  I would definitely buy one.

alex71m-zz, 2021-04-18:
would it also possible to by the unit from you?

zapta, 2021-04-18:
Hi Alex,

Unfortunately I don't have the capabilities to manufacture them so put them
in the public domain with no commercial restrictions with the hope that
some entrepreneur will manufacture and make them available to the community.

Zapta.

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

alex71m-zz, 2021-04-18:
> Hi Alex, Unfortunately I don't have the capabilities to manufacture them so put them in the public domain with no commercial restrictions with the hope that some entrepreneur will manufacture and make them available to the community. Zapta.
> […](#)
> On Sun, Apr 18, 2021 at 1:50 AM alex71m-zz ***@***.***> wrote: would it also possible to by the unit from you? — You are receiving this because you commented. Reply to this email directly, view it on GitHub <[#1 (comment)](https://github.com/zapta/simple_stepper_motor_analyzer/issues/1#issuecomment-821956982)>, or unsubscribe <https://github.com/notifications/unsubscribe-auth/AAQVMQK33EL6SHOA2PREKSDTJKMMLANCNFSM43DBLHNA> .

Hi Zapta

interesting...I can try to manufacture a small batch of this project and sell it on my website.
If you are interested in this kind of cooperation visit www-fm-laser.ch and get in contact with me through the contact form, ok?

Take care and hear you soon,
Alex

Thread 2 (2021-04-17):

Request: Provide XLS BOM?

bepstein111, 2021-04-17:
Hi there! This project looks great! My only request is to upload an XLS BOM so that people who don't want to source the individual surface mount components can just have the fab assemble that part.

Thanks for your hard work!

zapta, 2021-04-17:
Will work on it. The BOM that Kicad generates is not that useful. I will create something manually. Not too many parts to list.

zapta, 2021-04-17:
Added BOM.  https://github.com/zapta/simple_stepper_motor_analyzer/tree/master/kicad

bepstein111, 2021-04-18:
Thanks!

bepstein111, 2021-04-18:
Crap, I forgot, they also need a CPL (pick and place) file. If that's not easy for you to produce, don't worry about it.

zapta, 2021-04-18:
Ben, is this is what you are looking for?  https://support.jlcpcb.com/article/84-how-to-generate-the-bom-and-centroid-file-from-kicad

I can try going over the instructions and export.  BTW, I looked at SMD service at JLCPCB but am not sure they have the exact Alegro current sensors.

bepstein111, 2021-04-18:
Yeah, that's it! Hmmm you checked on LCSC.com? That's unfortunate. I wonder if I'd have better luck through PCBway?

coelholm, 2021-04-25:
@bepstein111 Did you have chance to generate that CPL file?

I found Alegro current sensor at [https://www.aliexpress.com/item/4000178092630.html](https://www.aliexpress.com/item/4000178092630.html)

phil-barrett, 2021-04-25:
Be very careful of aliexpress vendors.  There is a reasonable chance you will get a fake chip. Personally, I would not trust them - way too many stories of remarked chips that aren't even close to what they claim to be.

zapta, 2021-04-25:
Here is another one. This is witha  a different package that most makers
would consider easier to solder (will require a minor PCB change).

https://www.aliexpress.com/item/4000178147058.html

On Sat, Apr 24, 2021 at 11:48 PM phil-barrett ***@***.***>
wrote:

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

zapta, 2021-06-01:
FYI, I just released an upgraded design which is based on the Raspberry Pi Pico. It also includes gerbers, bom and pos files for JLCPCB SMD service, for the parts they do carry.

https://github.com/zapta/simple_stepper_motor_analyzer

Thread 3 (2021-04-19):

Would a voltage reading be possible?

pfn, 2021-04-19:
Seems like the galvanic isolation would prevent this, though  :(

zapta, 2021-04-19:
Yes, that's correct, sampling also the coil's voltage will allow to provide additional information. I didn't use that approach to keep the design simple. Hopefully the idea of stepper analyzer will get wider attention by the community and others will come with new features and capabilities.

This concept can evolve in many directions. One of the options I considered is a small dongle, that connects in serial to the stepper, has no screen or USB connector, derives the (minimal) power from the stepper motor, and sends the data to a computer app via BLE. A dongle like that could also sample the coil voltages.

phil-barrett, 2021-04-24:
Another possibility is to use an isolating I2C or SPI interface.  I have used an ISO1540 to isolate the sampling side of a high voltage system.  See the schematic below.  It is used to sample a plasma torch height signal (100-120VDC).

That brings up the question of power.  I punted on it in the project below - requiring an external isolated 9-12V power input. The sampling dongle could be battery powered (2032 coin cell probably). Though for good battery life, it would probably need a small microcontroller to manage shut down/wake up.

Perhaps better to figure out how to draw a little parasitic power from the steppers. A few mA wouldn't change things much.

Worst case is an isolated DC-DC converter.

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

zapta, 2021-04-25:
The digital isolator is very interesting. A few things to address:

1. Isolated power.  An isolateddc/dc is one possible solution. E.g.
AM1SS-0503SJZ. Harvesting power from the stepper is also interesting.

2. Lack of access to stepper ground. One brute force approach is to have to
independent isolated channels, one for each coil.

3. Sampling rate. The sampling rate needs to be fast enough (currently the
analyzer sample current at 100k samples/sec) and possibly in sync with the
current samplings.

I wonder what kind of analysis adding the voltage sampling will allow. For
example can it be used to compute the inductance or back EMF?  Can it be
used to detect skipped steps, similar to the stall detection done by the
TMC stepper drivers? Anything else?

I would start with a quick and one of sampling of current and voltages as a
proof of concept that useful data can be extracted from it.

Z.

On Sat, Apr 24, 2021 at 9:36 AM phil-barrett ***@***.***>
wrote:

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

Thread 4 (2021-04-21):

ACS70331 unavailable

pbinsted, 2021-04-21:
It appears this chip is no longer available.

pelrun, 2021-04-23:
According to who? Allegro still says it's an active line item.

Remember that current global conditions mean that many parts are in incredibly short supply and have extreme lead times. Many suppliers may simply be unable to get stock until 2022.

phil-barrett, 2021-04-23:
Use Octopart or Findchips to find distributors.  There are parts available.  Even the SOIC chips (ES) are available.

pbinsted, 2021-04-23:
ah ok, thanks for clearing that up. I'll just have to be patient!

zapta, 2021-04-24:
@pelrun is right, there is a general shortage of semiconductors. I got mine from Digikey in small quantities but now temporarily our of order. If anybody finds a source please share it here.  Bad time to announce a new open source design ;-)

zapta, 2021-06-01:
FYI, I just released a new design of the analyzer which is based on a bare TFT panel (cheaper), Raspberry Pi Pico module (more ram/rom/speed than STM32) and SOIC-8 current sensors that are available on Aliexpress.

https://github.com/zapta/simple_stepper_motor_analyzer

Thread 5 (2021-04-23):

Alternative Sensor?

phil-barrett, 2021-04-23:
Hi, cool project here.  I see a number of ways this could be taken.  My first question is about the sensor.  It is rated for up to 2.5A. My experience is that to be really safe I need to derate.  Have you played with any bidirectional sensors that work at higher currents?  I see Allegro has quite a few.

Have you looked at the [ACS712](https://datasheet.lcsc.com/szlcsc/Allegro-MicroSystems-LLC-ACS712ELCTR-20A-T_C10681.pdf)? It claims to handle up to 20A.  Does that make your readings too coarse? I suppose I should dig through the code...

zapta, 2021-04-24:
Allegro has a +/-5A unit that should fit on the same board. Need to tell
the firmware through to scale the current readings by x2. For another, non
related project, I am using  ACS781LLRTR-050U-T which is unidirectional and
for higher currents and it works just fine.

The ACS712 you mentioned  has a +/-5A version and an easier to solder
package, but its bandwidth is only 80Khz, which may or may not be
sufficient, need to think more about it. BTW, the analyzer samples as
100Khz.

BTW, it's also available on JLCPCB as a standard part for SMT assembly so
this is also a plus
https://jlcpcb.com/parts/componentSearch?isSearch=true&searchTxt=ACS712

On Fri, Apr 23, 2021 at 9:07 AM phil-barrett ***@***.***>
wrote:

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

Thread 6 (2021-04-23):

Display performance requirements

phil-barrett, 2021-04-23:
What kind of performance do you need from the display?  Since you went with a parallel interface, I assume that you need fast updates.  There are lots of inexpensive displays that use SPI - too slow for your needs?

By the way, I am posting in Issues though these aren't really "issues".  If you turned on Discussions - I would put them there.  I think your project has a lot of potential for derivative projects and variant hardware. Perhaps Discussions would be a better place to talk about that?

zapta, 2021-04-24:
Display performance was an important part of the design and I went through
a few iterations. SPI would be the easiest since its' supported by DMA
which will allow rendering in memory and sending to the display at the same
time. However, the ILI9488 datasheet specifies max SPI speed of ~15Mhz
which is about 1M pixels/sec. (16 bits each). With the parallel interface
the analyzer archives about 10M pixels/secs, including color mapping from 8
bit pixels in memory (to save RAM) to 16 bit pixels required by the ILI9488.

You are right about the potential for derivative projects, e.g. cutting
cost using a display-less unit that connects to a phone or a computer via
USB (sensors are galvanically isolated so should be safe) or BLE. Another
option is to have a board that supports multiple sensors (e.g. to determine
x/y/z of a delta or corexy printer).  You can see this design as a proof of
concept that hopefully inspire ideas and products.

On Fri, Apr 23, 2021 at 9:13 AM phil-barrett ***@***.***>
wrote:

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

zapta, 2021-06-01:
FYI, I just released a new design which uses a bare TFT panel and the Raspberry Pi Pico. The screen update rate with that design is 12M pixels/sec which is equivalent to 192Mhz SPI.

https://github.com/zapta/simple_stepper_motor_analyzer

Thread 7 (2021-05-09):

Compatible TFT screens / or replacements

vakuliniv, 2021-05-09:
Can I replace the screen from your project by this https://aliexpress.ru/item/4000302982264.htm ?
May be you have list of compatible screens?

zapta, 2021-05-09:
When I tried to access your aliexpress link got an error page.

The TFT is very speciried 320x480, ILI9488 controller, capacitive touch
screen, and 16 bit parallel data pins. I spent a lot of time on aliexpress
and didn't find any better than the one from buydisplay.com which is also a
stable source.

Recently somebody pointed me to the "3.5 LCD CTP" here and I ordered two
for evaluation. If it will work, it will require some changes in the PCB.

https://www.aliexpress.com/item/32862869103.html?spm=a2g0s.9042311.0.0.481c4c4dHx7266

For now, I strongly recommend getting the one from buydisplay.com.

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

vakuliniv, 2021-05-09:
Sorry, that is right link
https://aliexpress.ru/item/4000302982264.html

as I can understand this screen is maximal close to original screen, perhaps.

I asked, because is some problems with delivery to my country from  buydisplay.com

zapta, 2021-05-09:
That's an interesting TFT module, thanks.

If you are handy with writing firmware you may make it to work. It seems to
have the same TFT controller, 16 bit parallel data lines and same
resolution. The main differences are the pins count and order (the
buydisplay.com has 40 pins and different order) but you may overcome with
this the proper wiring. And more important, its touch uses SPI rather than
I2C so you will need to modify the touch driver and again, wire it to the
SPI pins of the blackpill though I am not sure if they are currently free.

Hope it helps,

Zapta

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

vakuliniv, 2021-05-10:
Thanks. I hope you inclide this display as compatible ( https://www.aliexpress.com/item/32862869103.html )
into the BOM .

zapta, 2021-05-10:
That display will require PCB changes and possible a few additional
components (e.g. resistor to drive the background LEDs).  I have it on
order and should arrive in a few weeks.  I am also experimenting with
replacing the blackpill MCU module with Raspberry Pi Pico. If it will go
well, it will provide a more stable source for the MCU module, will see how
that will go.  In any case, if this will work, it will take months for the
new design to be available.

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

zapta, 2021-06-01:
FYI, I just released a new design which is based on a bare TFT (cheaper) and the Raspberry Pi Pico (more RAM, ROM, speed).

https://github.com/zapta/simple_stepper_motor_analyzer

It also include a general BOM and in the JLCPCB directory bom and pos file for the JLCPCB SMD service for some of the parts.

https://github.com/zapta/simple_stepper_motor_analyzer

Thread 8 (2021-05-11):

Need your help

823878209, 2021-05-11:
Dear blogger:
       I'm a college student from China. I made a machine by myself according to your steps. After the assembly is completed and the firmware is burned, it can't be displayed normally. It's just a white screen. I bought the left and right components according to the BOM provided by you. Can you help me solve this problem? If you can, I hope you can contact me. Thank you!
Mailbox: 823878209@qq.com

zapta, 2021-05-13:
Hi 823878209, can you post here a picture of your build?

823878209, 2021-05-13:
------------------ 原始邮件 ------------------
发件人:                                                                                                                        "zapta/simple_stepper_motor_analyzer"                                                                                    ***@***.***&gt;;
发送时间:&nbsp;2021年5月13日(星期四) 上午9:59
***@***.***&gt;;
***@***.******@***.***&gt;;
主题:&nbsp;Re: [zapta/simple_stepper_motor_analyzer] Need your help (#8)

 Dear zapta, hello, first of all thank you for replying to me.

&nbsp;&nbsp;&nbsp; &nbsp; According to the open source document you posted on GitHub, I found the Gerber file and completed the PCB proofing. I purchased all the components according to the BOM. After I assembled as required, I burned the program and my LCD screen was running. The correct content is not displayed on the screen, and he is always in a white screen state.

&nbsp;&nbsp;&nbsp; &nbsp; After the assembly was completed, I burned the program, and it ran for the first time, and a part of the content was displayed on the LCD screen but it was incomplete, and then I ran it again and the situation in the picture below appeared.

&nbsp;&nbsp;&nbsp; &nbsp; Since I didn’t get in touch with you in time, I thought it was a problem with the LCD screen. I contacted the LCD manufacturer. They said that the LCD screen I purchased might be different from your model. I carefully compared the BOM table. The problem, I also showed them and they said there was no problem,

&nbsp;&nbsp;&nbsp; &nbsp; Finally, the LCD screen manufacturer told me that I need to contact you, take a look at the photo on the back of the LCD screen you are using, and see how the components on it are distributed.

&nbsp;&nbsp;&nbsp;&nbsp; &nbsp; This is my confusion and problem. I can't find the problem with my machine, so I ask you for advice and study.

823878209, 2021-05-13:
Dear zapta, hello, first of all thank you for replying to me.

      According to the open source document you posted on GitHub, I found the Gerber file and completed the PCB proofing. I purchased all the components according to the BOM. After I assembled as required, I burned the program and my LCD screen was running. The correct content is not displayed on the screen, and he is always in a white screen state.

      After the assembly was completed, I burned the program, and it ran for the first time, and a part of the content was displayed on the LCD screen but it was incomplete, and then I ran it again and the situation in the picture below appeared.

      Since I didn’t get in touch with you in time, I thought it was a problem with the LCD screen. I contacted the LCD manufacturer. They said that the LCD screen I purchased might be different from your model. I carefully compared the BOM table. The problem, I also showed them and they said there was no problem,

      Finally, the LCD screen manufacturer told me that I need to contact you, take a look at the photo on the back of the LCD screen you are using, and see how the components on it are distributed.

       This is my confusion and problem. I can't find the problem with my machine, so I ask you for advice and study.
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

823878209, 2021-05-13:
------------------ 原始邮件 ------------------
发件人:                                                                                                                        "zapta/simple_stepper_motor_analyzer"                                                                                    ***@***.***&gt;;
发送时间:&nbsp;2021年5月13日(星期四) 上午9:59
***@***.***&gt;;
***@***.******@***.***&gt;;
主题:&nbsp;Re: [zapta/simple_stepper_motor_analyzer] Need your help (#8)

 Dear zapta, hello, first of all thank you for replying to me.

&nbsp; &nbsp; &nbsp; According to the open source document you posted on GitHub, I found the Gerber file and completed the PCB proofing. I purchased all the components according to the BOM. After I assembled as required, I burned the program and my LCD screen was running. The correct content is not displayed on the screen, and he is always in a white screen state.

&nbsp; &nbsp; &nbsp; After the assembly was completed, I burned the program, and it ran for the first time, and a part of the content was displayed on the LCD screen but it was incomplete, and then I ran it again and the situation in the picture below appeared.

&nbsp; &nbsp; &nbsp; Since I didn’t get in touch with you in time, I thought it was a problem with the LCD screen. I contacted the LCD manufacturer. They said that the LCD screen I purchased might be different from your model. I carefully compared the BOM table. The problem, I also showed them and they said there was no problem,

&nbsp; &nbsp; &nbsp; Finally, the LCD screen manufacturer told me that I need to contact you, take a look at the photo on the back of the LCD screen you are using, and see how the components on it are distributed.

&nbsp;&nbsp; &nbsp; &nbsp; This is my confusion and problem. I can't find the problem with my machine, so I ask you for advice and study.

zapta, 2021-05-13:
Hello 823878209,

I like your build.

Here is a video that shows how my board behaves https://imgur.com/SCAhCDZ.
It does not matter if the TFT is connected or not.

Do you get the same LED blinking pattern and similar output on the
terminal?

Zapta

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

823878209, 2021-05-13:
Thank you very much for your help. I just watched your video.&nbsp;

The LED working status of my device is the same as your video.&nbsp;

I just tried to use the serial port assistant to read the information of the device.&nbsp;

The information shown in the video, but my LCD screen still does not display any information, is there something wrong with my LCD screen?

I also need to ask you, do the three BIN files in the open source file have any different functions? (Firmware-2021-02-01, firmware-2021-02-01, firmware-2021-02-01)

------------------&nbsp;原始邮件&nbsp;------------------
发件人:                                                                                                                        "zapta/simple_stepper_motor_analyzer"                                                                                    ***@***.***&gt;;
发送时间:&nbsp;2021年5月13日(星期四) 晚上10:32
***@***.***&gt;;
***@***.******@***.***&gt;;
主题:&nbsp;Re: [zapta/simple_stepper_motor_analyzer] Need your help (#8)

 Hello 823878209,

 I like your build.

 Here is a video that shows how my board behaves https://imgur.com/SCAhCDZ.
 It does not matter if the TFT is connected or not.

 Do you get the same LED blinking pattern and similar output on the
 terminal?

 Zapta

 On Wed, May 12, 2021 at 8:29 PM 823878209 ***@***.***&gt; wrote:

 &gt; ------------------ 原始邮件 ------------------
 &gt; 发件人: "zapta/simple_stepper_motor_analyzer" ***@***.***&amp;gt;;
 &gt; 发送时间:&amp;nbsp;2021年5月13日(星期四) 上午9:59
 &gt; ***@***.***&amp;gt;;
 &gt; ***@***.******@***.***&amp;gt;;
 &gt; 主题:&amp;nbsp;Re: [zapta/simple_stepper_motor_analyzer] Need your help (#8)
 &gt;
 &gt;
 &gt;
 &gt;
 &gt;
 &gt; Dear zapta, hello, first of all thank you for replying to me.
 &gt;
 &gt; &amp;nbsp; &amp;nbsp; &amp;nbsp; According to the open source document you posted on
 &gt; GitHub, I found the Gerber file and completed the PCB proofing. I purchased
 &gt; all the components according to the BOM. After I assembled as required, I
 &gt; burned the program and my LCD screen was running. The correct content is
 &gt; not displayed on the screen, and he is always in a white screen state.
 &gt;
 &gt;
 &gt; &amp;nbsp; &amp;nbsp; &amp;nbsp; After the assembly was completed, I burned the
 &gt; program, and it ran for the first time, and a part of the content was
 &gt; displayed on the LCD screen but it was incomplete, and then I ran it again
 &gt; and the situation in the picture below appeared.
 &gt;
 &gt;
 &gt; &amp;nbsp; &amp;nbsp; &amp;nbsp; Since I didn’t get in touch with you in time, I
 &gt; thought it was a problem with the LCD screen. I contacted the LCD
 &gt; manufacturer. They said that the LCD screen I purchased might be different
 &gt; from your model. I carefully compared the BOM table. The problem, I also
 &gt; showed them and they said there was no problem,
 &gt;
 &gt;
 &gt; &amp;nbsp; &amp;nbsp; &amp;nbsp; Finally, the LCD screen manufacturer told me that I
 &gt; need to contact you, take a look at the photo on the back of the LCD screen
 &gt; you are using, and see how the components on it are distributed.
 &gt;
 &gt;
 &gt; &amp;nbsp;&amp;nbsp; &amp;nbsp; &amp;nbsp; This is my confusion and problem. I can't find
 &gt; the problem with my machine, so I ask you for advice and study.
 &gt;
 &gt; —
 &gt; You are receiving this because you commented.
 &gt; Reply to this email directly, view it on GitHub
 &gt; <https://github.com/zapta/simple_stepper_motor_analyzer/issues/8#issuecomment-840266078&gt;,
 &gt; or unsubscribe
 &gt; <https://github.com/notifications/unsubscribe-auth/AAQVMQJEMLOSQDSD43W3JL3TNNBRTANCNFSM44UNR6ZA&gt;
 &gt; .
 &gt;

—
You are receiving this because you authored the thread.
Reply to this email directly, view it on GitHub, or unsubscribe.

zapta, 2021-05-13:
Hello 823878209,

1. Please use the binary with the latest date. This is the latest version.

2. Can you send me a picture of your TFT PCB. I want to look at the jumpers
and resistors to see that you have the proper version.
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
zapta, 2021-05-13:
I modified my TFT for a different project. Ignore the areas marked in red.
Everything else should be like your TFT.

Your TFT seems to have the FONT chip. Did you order it from buydisplay.com with
the FONT chip?  I never tried a TFT with a FONT chip.

Also, when you will get your TFT back from the vendor, try to connect the
resistor and tell me if it solves the problem..

https://imgur.com/Vo2hg8B

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

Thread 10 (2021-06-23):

Open 3D files?

MarcelRobitaille, 2021-06-23:
The 3D folder only has `.stl` files. Would it be possible to have them as a step or similar?

zapta, 2021-06-23:
These are the two onshape projects. Can you see them? Can you export in the
format of your choice?

https://cad.onshape.com/documents/146b8b994145177887407b23/v/0a1e5f034a5403b7d545e8f5/e/b6453eca2ba530476c30538a

https://cad.onshape.com/documents/c2cb2c3a5f0213b18ca23aa6/v/0c557975f7362fe0b01ac51c/e/1478128b17ff3afd79bedf8b

On Wed, Jun 23, 2021 at 1:25 PM Marcel Robitaille ***@***.***>
wrote:

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

MarcelRobitaille, 2021-06-23:
That is better than a step. I use OnShape too. Thank you so much.

Closed 2021-06-23.

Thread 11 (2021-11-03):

QFN-12 to SOIC8 replace

vakuliniv, 2021-11-03:
Dear author, in your project "Legacy_stepper_motor_analyser" you used current sensors ACS70331EESATR-2P5B3 (x2 QFN-12 chip ). Can you make light redesign of the board and add place for SOIC-8 version of current sensors (ACS70331EOLCTR-2P5B3), or fully change places ( x2 QFN-12 to  x2 SOIC-8)? This is problem for me to find sensor in QFN-12 chip with adequate price :(  The SOIC-8 version is widely presented in available stores. I'm sorry, but I haven't enough time to deal with Kicad now :(. Alas, migrate to Raspbery PI is not acceptable variant too. Best regards

zapta, 2021-11-04:
Hello  vakuliniv,

Have you looked at the new design? It uses a different package of the same
IC.

https://github.com/zapta/simple_stepper_motor_analyzer

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

vakuliniv, 2021-11-04:
Hello, zapta.
Yes, I saw your new design :) But it was designed for Raspbery Pi :( This is not entirely convenient for me ... I would like to use exactly  STM32 version by some reasons. Therefore, my request remains valid. I hope, it will be easy for you to made this changes.

zapta, 2021-11-05:
Hi  vakuliniv,  sorry but I don't have an SOIC version of the legacy design
and I don't maintain it any more (that's why I renamed to 'legacy').

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

vakuliniv, 2021-11-07:
Hello, zapta. I had to master the basics of the KiCad and make changes to the design myself. Now  legacy project has board with SOIC-8 footprint. Are you need this version?

zapta, 2021-11-07:
Hi vakuliniv, thanks for the offer. I prefer not to touch the legacy
version and focus on the new design because it's based on the Raspberry
Pico (a superior MCU) and a less expensive bare TFT that also allows a more
compact case.

Good luck with the project. It's a lot of fun.

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

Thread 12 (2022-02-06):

ACS70331 equivalent/alternative

springsteenrob, 2022-02-06:
The ACS70331 is not available anywhere. Is there an alternative/equivalent to use

zapta, 2022-02-06:
Some people reported that they successfully used the TMCS1101A4BQDT as a
drop in replacement, though don't have personal experience with it.

https://forum.duet3d.com/topic/23461/anybody-wants-a-stepper-motor-analyzer/180?_=1644177022197

On Sun, Feb 6, 2022 at 11:20 AM springsteenrob ***@***.***>
wrote:

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

springsteenrob, 2022-02-06:
Thank you for your quick response.
I have ordered the drop in replacement and I will let you know the outcome

Best Regards

Sent from my iPhone

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

zapta, 2022-02-07:
Great!  These are difficult times for sourcing parts.

Looking forward to seeing how it worked for you.

On Sun, Feb 6, 2022 at 12:34 PM springsteenrob ***@***.***>
wrote:

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

springsteenrob, 2022-03-17:
Hello,

I promised you to come back on the outcome of the alternative part : TMCS1101A4BQDT

I have one analyzer with the ACS70331EOLCTR AND one with the  TMCS1101A4BQDT

The one with the  TMCS1101A4BQDT does not work very well for me:

It counts steps in the Home menu  when motor are not moving and for example the current by step/sec read out is not stable (current varies and with the ACS70331 not)

Also the graphs are less crispy and contain noisy lines. The lines with the  ACS70331 are sharper.

So for me it is not an good drop in replacement.

Best Regards,

Rob

Van: Zapta ***@***.***>
Verzonden: Monday, February 07, 2022 4:01 AM
Aan: zapta/legacy_stepper_motor_analyzer ***@***.***>
CC: springsteenrob ***@***.***>; Author ***@***.***>
Onderwerp: Re: [zapta/legacy_stepper_motor_analyzer] ACS70331 equivalent/alternative (Issue #12)

Great! These are difficult times for sourcing parts.

Looking forward to seeing how it worked for you.

On Sun, Feb 6, 2022 at 12:34 PM springsteenrob ***@***.*** <mailto:***@***.***> >
wrote:

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

—
Reply to this email directly, view it on GitHub <https://github.com/zapta/legacy_stepper_motor_analyzer/issues/12#issuecomment-1031023139> , or unsubscribe <https://github.com/notifications/unsubscribe-auth/AXUMWEPEC2ALIFJ6N5GEYH3UZ4YW7ANCNFSM5NVWVGBQ> .
Triage notifications on the go with GitHub Mobile for iOS <https://apps.apple.com/app/apple-store/id1477376905?ct=notification-email&mt=8&pt=524675>  or Android <https://play.google.com/store/apps/details?id=com.github.android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> .
You are receiving this because you authored the thread.  <https://github.com/notifications/beacon/AXUMWEKDJITFHOVKZ7R6U63UZ4YW7A5CNFSM5NVWVGB2YY3PNVWWK3TUL52HS4DFVREXG43VMVBW63LNMVXHJKTDN5WW2ZLOORPWSZGOHV2CUIY.gif> Message ID: ***@***.*** ***@***.***> >

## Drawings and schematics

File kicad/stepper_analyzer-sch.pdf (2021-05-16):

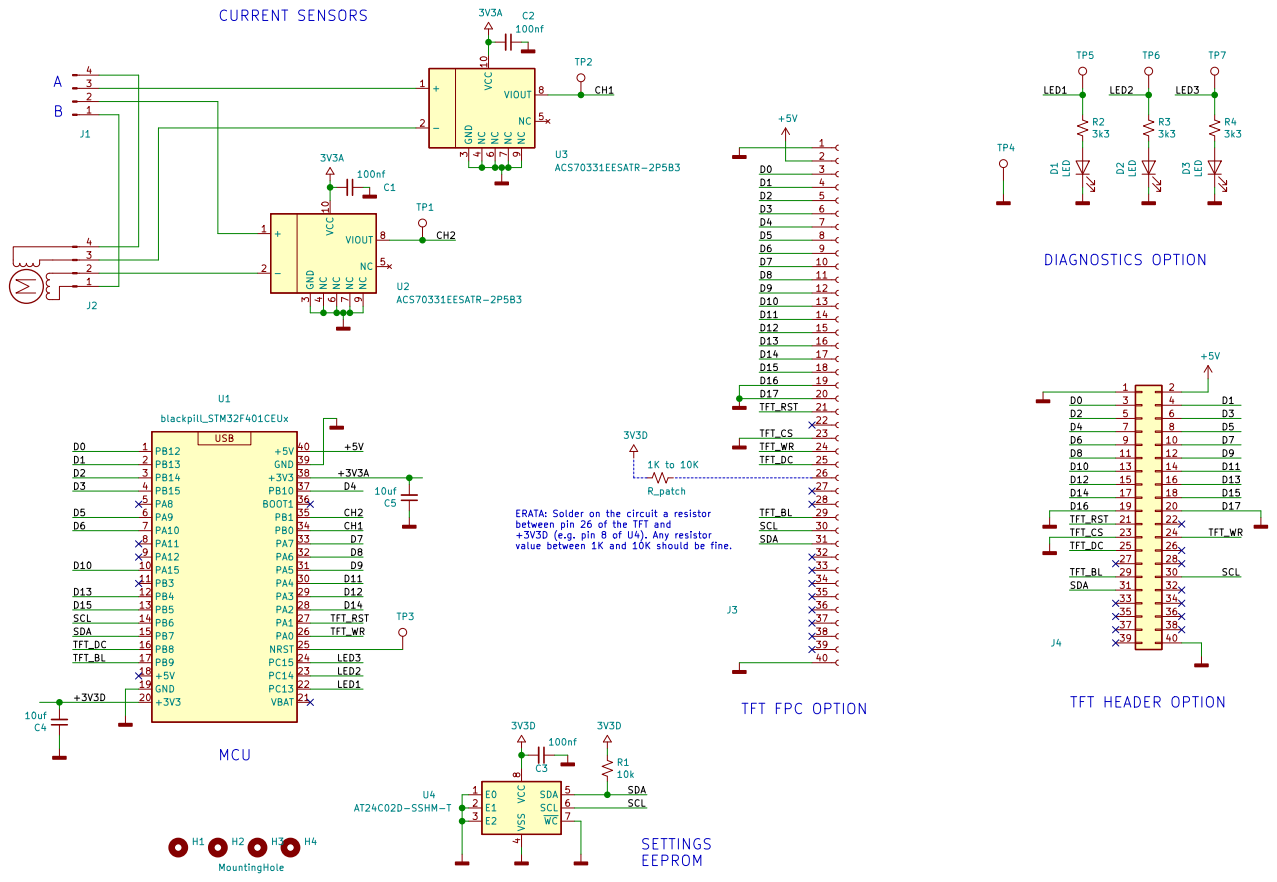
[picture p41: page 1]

ERATA: Solder on the circuit a resistor between pin 26 of the TFT and

+3V3D (e.g. pin 8 of U4). Any resistor value between 1K and 10K should be fine.

TFT HEADER OPTION TFT FPC OPTION

4 SDA 5 SCL 6 WC 7 VCC

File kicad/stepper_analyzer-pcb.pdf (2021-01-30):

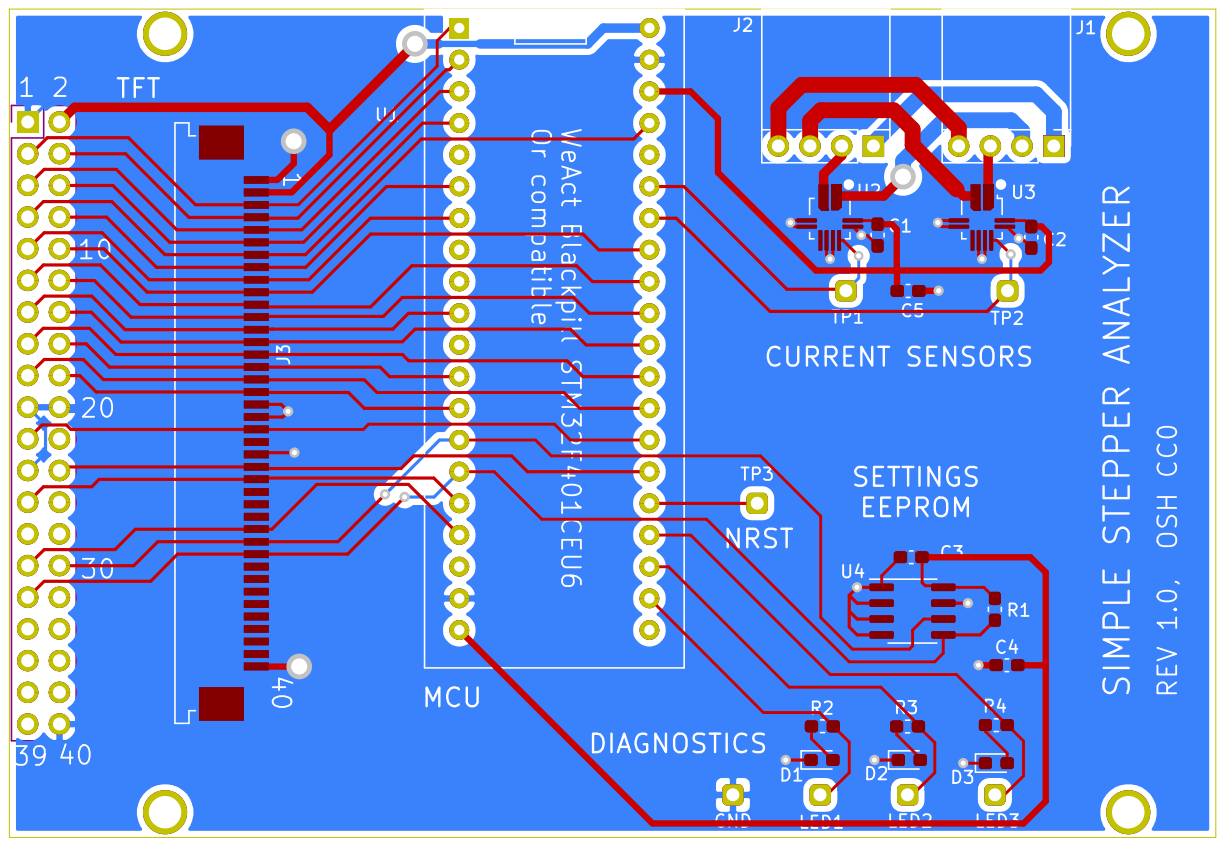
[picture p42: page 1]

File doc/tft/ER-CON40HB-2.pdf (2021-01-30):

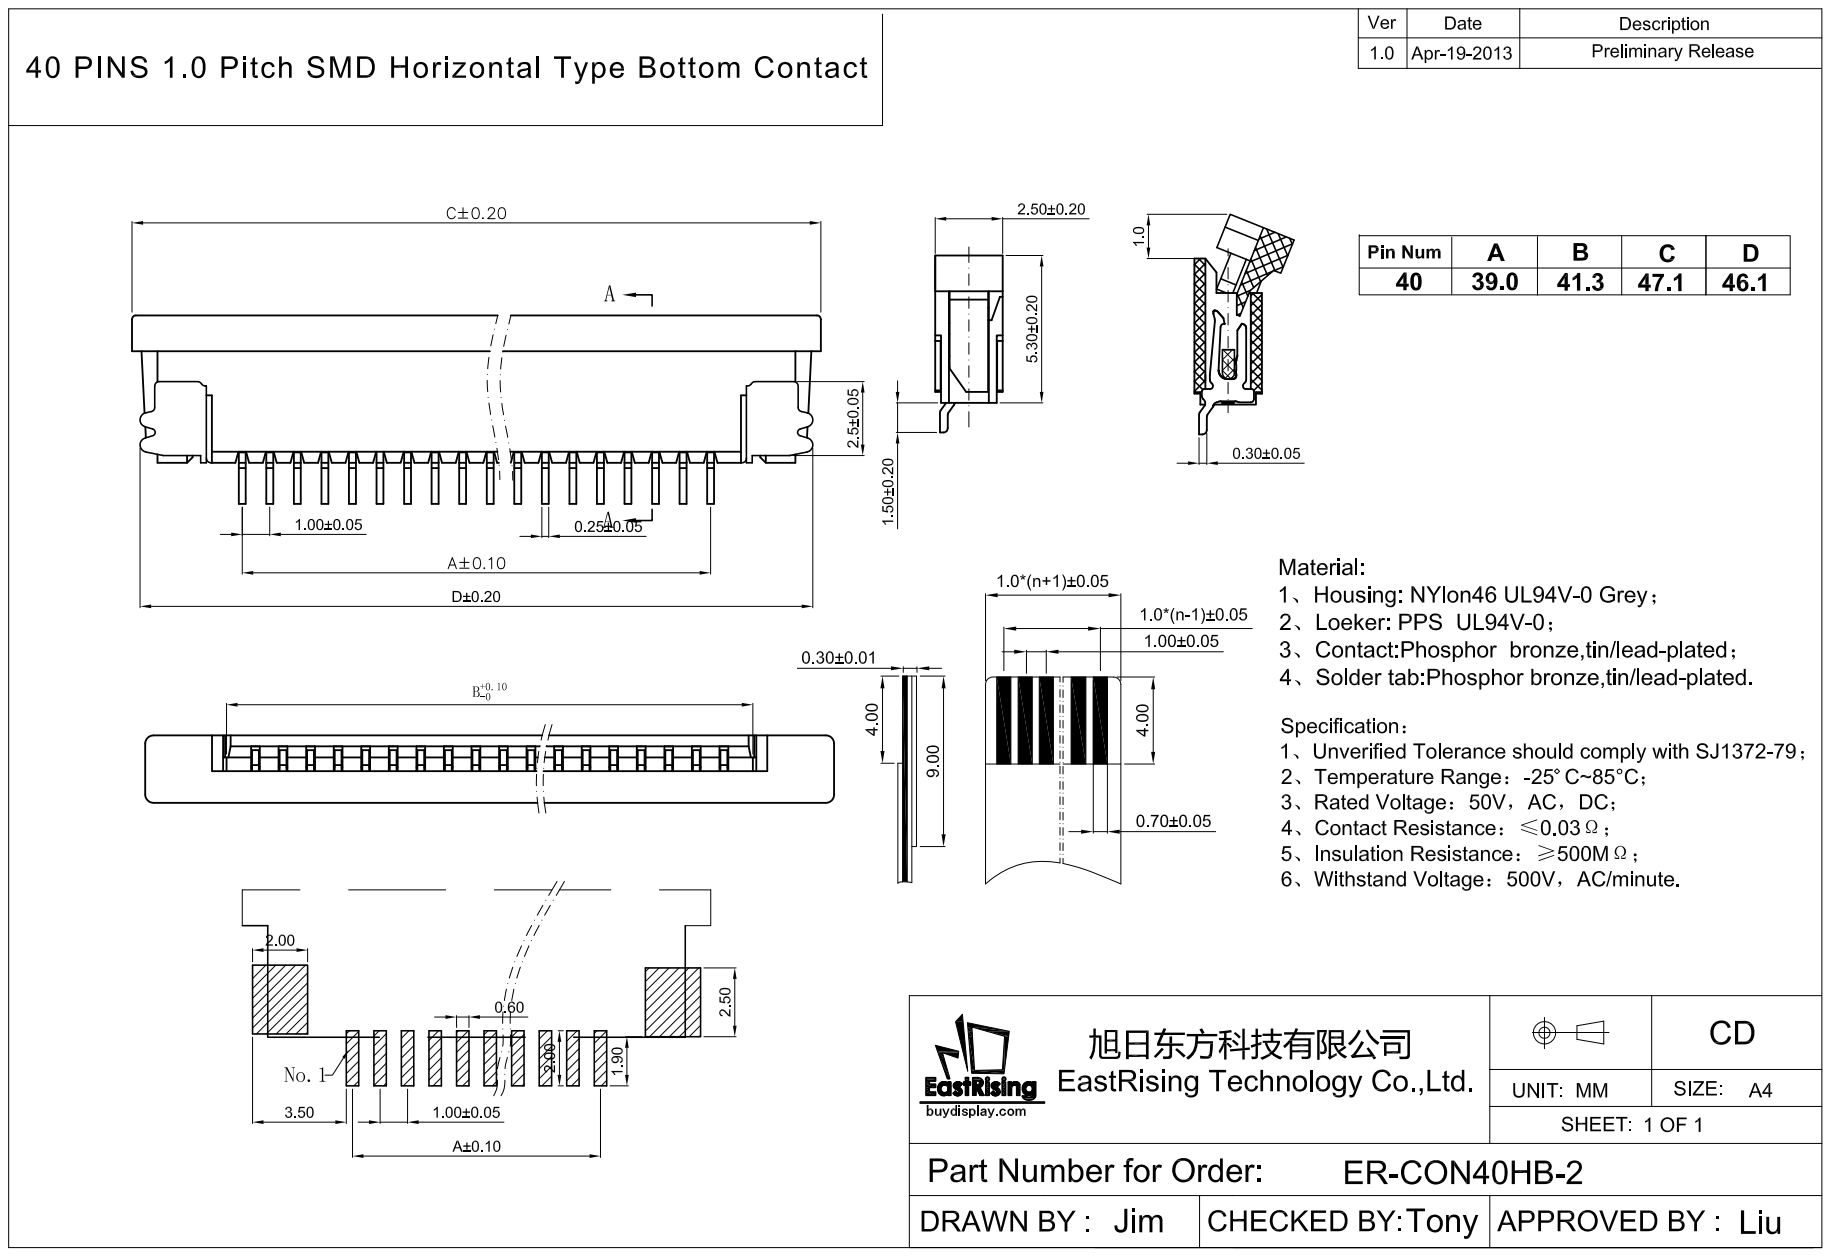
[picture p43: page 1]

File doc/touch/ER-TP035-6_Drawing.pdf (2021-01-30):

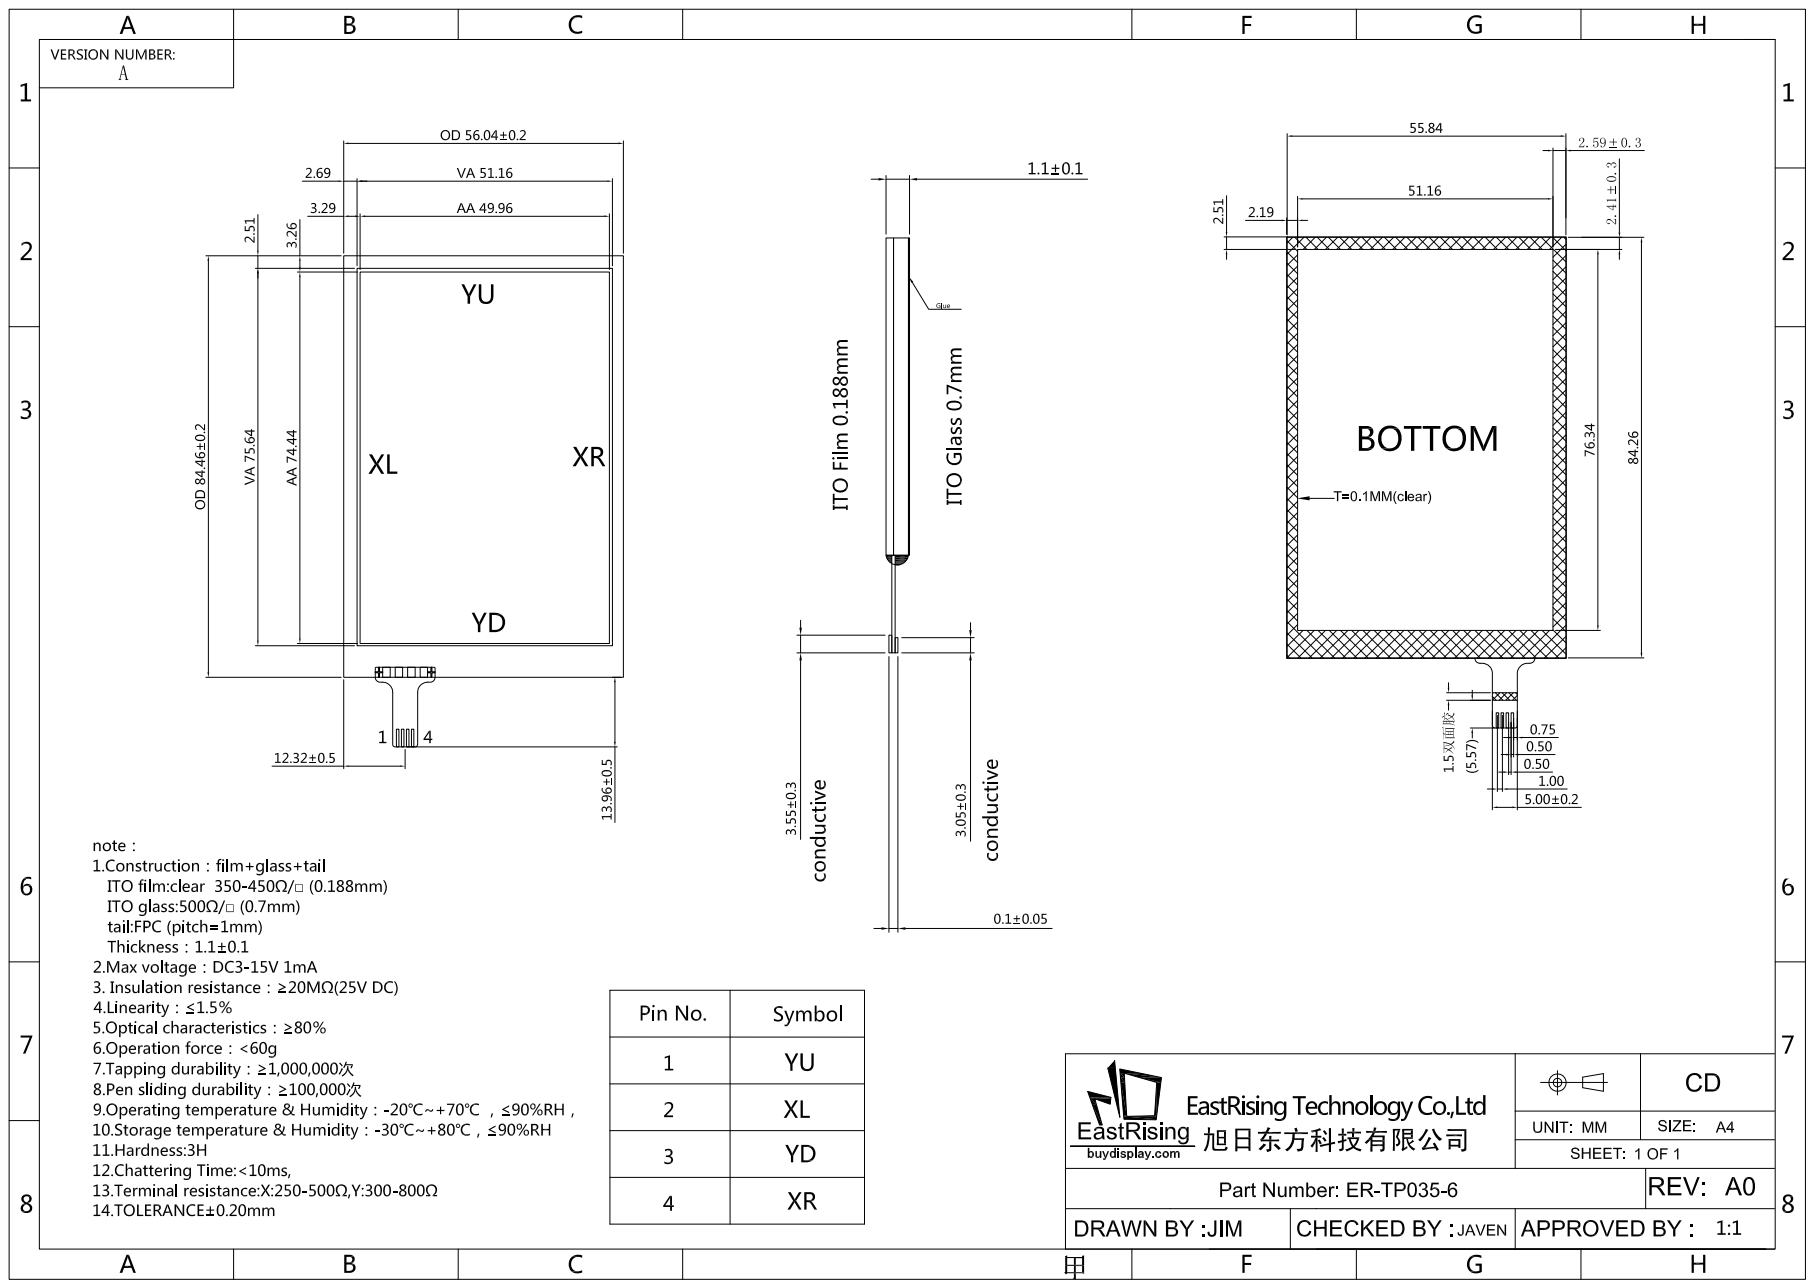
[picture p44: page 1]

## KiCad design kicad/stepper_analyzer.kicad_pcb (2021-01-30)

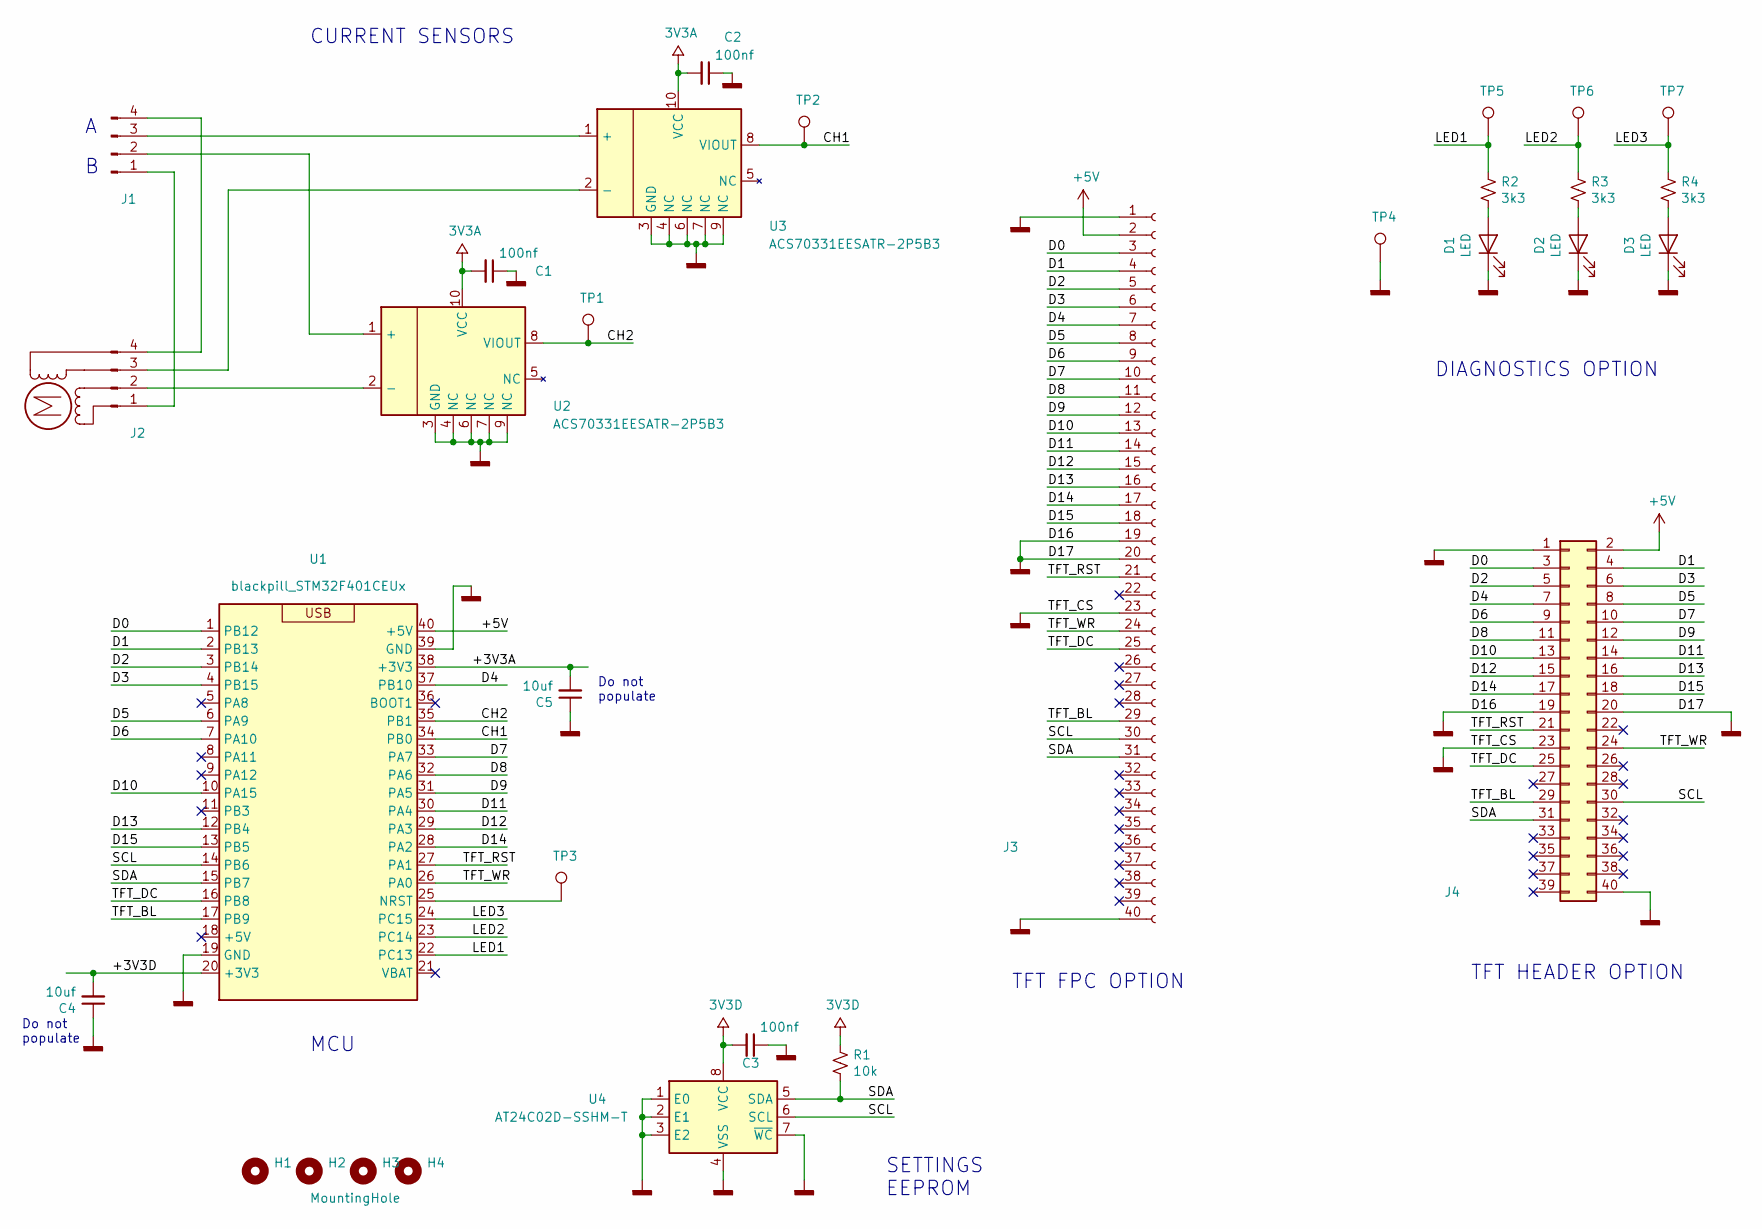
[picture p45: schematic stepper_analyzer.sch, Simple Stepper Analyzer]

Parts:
C1, C2, C3: 100nf; C_0603_1608Metric_Pad1.08x0.95mm_HandSolder
C4, C5: 10uf; C_0603_1608Metric_Pad1.08x0.95mm_HandSolder
D1, D2, D3: LED; LED_0603_1608Metric_Pad1.05x0.95mm_HandSolder
H1, H2, H3, H4: MountingHole
J1, J2: Conn_01x04_Male; connector_4pins_horizontal
J3: Conn_01x40_Female; FPC_connector_40P_1.0mm
J4: Conn_02x20_Odd_Even; PinSocket_2x20_P2.54mm_Vertical
M1: Stepper_Motor_bipolar; null_footprint
R1: 10k; R_0603_1608Metric_Pad1.05x0.95mm_HandSolder
R2, R3, R4: 3k3; R_0603_1608Metric_Pad1.05x0.95mm_HandSolder
TP1, TP2, TP3, TP4, TP5, TP6, TP7: TestPoint; testpoint
U1: blackpill_STM32F401CEUx; blackpill_module
U2, U3: ACS70331EESATR-2P5B3; Allegro_QFN-12-10-1EP_3x3mm_P0.5mm
U4: AT24C02D-SSHM-T; SOIC-8_3.9x4.9mm_P1.27mm

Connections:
+5V: J3.2, J4.2, U1.40 (+5V)
/CH1: TP2.1, U1.34 (PB0), U3.8 (VIOUT)
/CH2: TP1.1, U1.35 (PB1), U2.8 (VIOUT)
/D0: J3.3, J4.3, U1.1 (PB12)
/D1: J3.4, J4.4, U1.2 (PB13)
/D2: J3.5, J4.5, U1.3 (PB14)
/D3: J3.6, J4.6, U1.4 (PB15)
/D4: J3.7, J4.7, U1.37 (PB10)
/D5: J3.8, J4.8, U1.6 (PA9)
/D6: J3.9, J4.9, U1.7 (PA10)
/D7: J3.10, J4.10, U1.33 (PA7)
/D8: J3.11, J4.11, U1.32 (PA6)
/D9: J3.12, J4.12, U1.31 (PA5)
/D10: J3.13, J4.13, U1.10 (PA15)
/D11: J3.14, J4.14, U1.30 (PA4)
/D12: J3.15, J4.15, U1.29 (PA3)
/D13: J3.16, J4.16, U1.12 (PB4)
/D14: J3.17, J4.17, U1.28 (PA2)
/D15: J3.18, J4.18, U1.13 (PB5)
/LED1: R2.1, TP5.1, U1.22 (PC13)
/LED2: R3.1, TP6.1, U1.23 (PC14)
/LED3: R4.1, TP7.1, U1.24 (PC15)
/SCL: J3.30, J4.30, U1.14 (PB6), U4.6 (SCL)
/SDA: J3.31, J4.31, R1.2, U1.15 (PB7), U4.5 (SDA)
/TFT_BL: J3.29, J4.29, U1.17 (PB9)
/TFT_DC: J3.25, J4.25, U1.16 (PB8)
/TFT_RST: J3.21, J4.21, U1.27 (PA1)
/TFT_WR: J3.24, J4.24, U1.26 (PA0)
GNDD: C1.1, C2.1, C3.1, C4.1, C5.1, D1.1 (K), D2.1 (K), D3.1 (K), J3.1, J3.19, J3.20, J3.23, J3.40, J4.1, J4.19, J4.20, J4.23, J4.40, TP4.1, U1.19 (GND), U1.39 (GND), U2.3 (GND), U2.4 (NC), U2.6 (NC), U2.7 (NC), U2.9 (NC), U3.3 (GND), U3.4 (NC), U3.6 (NC), U3.7 (NC), U3.9 (NC), U4.1 (E0), U4.2 (E1), U4.3 (E2), U4.4 (VSS), U4.7 (~WC)
unnamed: D1.2 (A), R2.2
unnamed: D2.2 (A), R3.2
unnamed: D3.2 (A), R4.2
unnamed: J1.1, J2.1
unnamed: J1.2, U2.1 (+)
unnamed: J1.3, U3.1 (+)
unnamed: J1.4, J2.4
unnamed: J2.2, U2.2 (-)
unnamed: J2.3, U3.2 (-)
unnamed: TP3.1, U1.25 (NRST)

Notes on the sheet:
MCU
SETTINGS EEPROM
CURRENT SENSORS
TFT HEADER OPTION
TFT FPC OPTION
DIAGNOSTICS OPTION
Do not populate

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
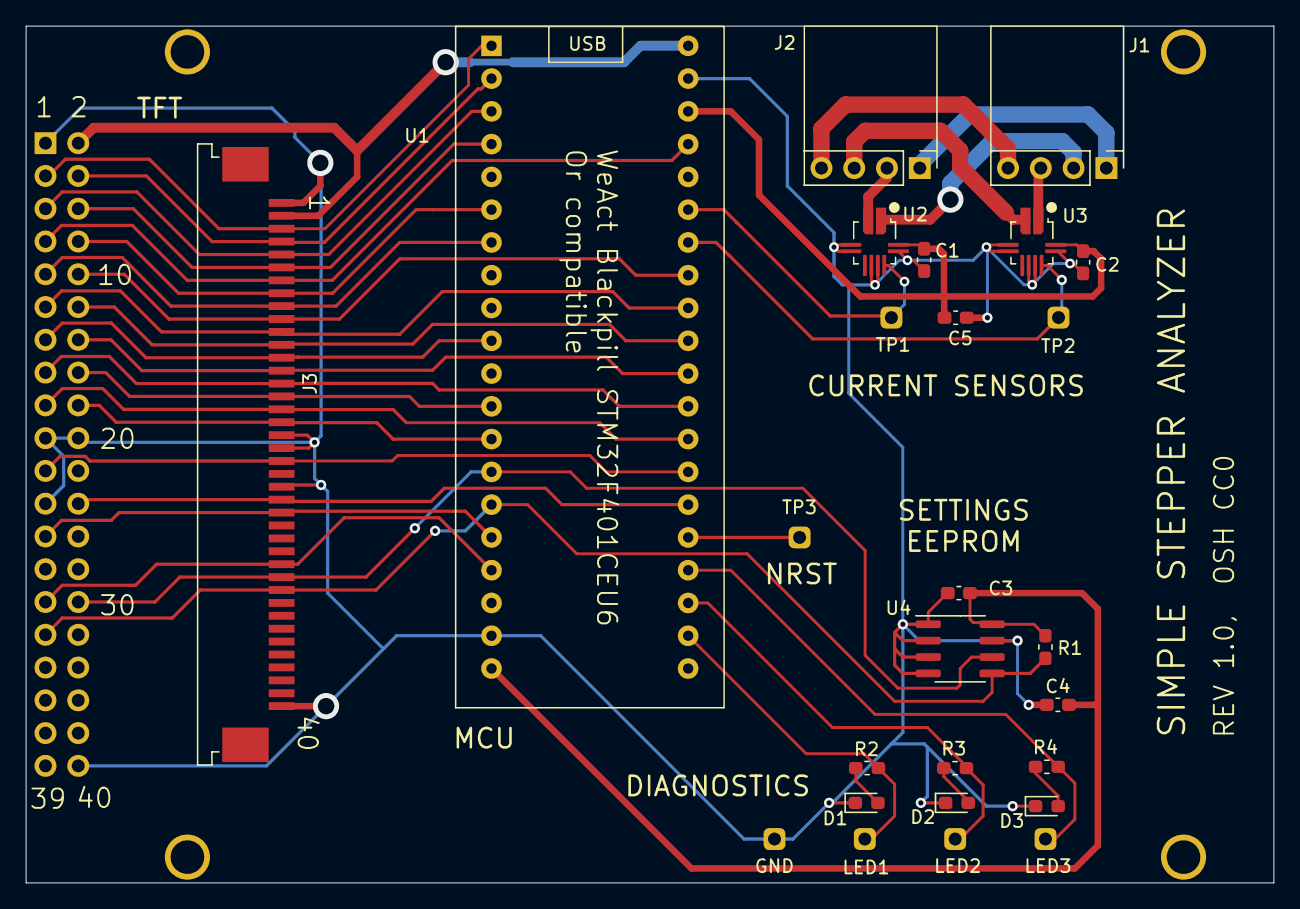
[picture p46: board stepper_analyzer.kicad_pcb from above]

Board: 2 copper layers, 96.7 x 66.4 mm, 32 parts (1 on the bottom side), 41 nets.

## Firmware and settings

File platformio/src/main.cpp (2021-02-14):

// Stepper Motor Analyzer.

#include <Arduino.h>

#include "analyzer/acquisition.h"
#include "display/lv_adapter.h"
#include "display/tft_driver.h"
#include "display/touch_driver.h"
#include "hal/adc.h"
#include "hal/dma.h"
#include "hal/gpio.h"
#include "hal/i2c.h"
#include "hal/tim.h"
#include "lvgl.h"
#include "misc/config_eeprom.h"
#include "misc/elapsed.h"
#include "misc/memory.h"
#include "ui/screen_manager.h"

// We assume an external crystal clock of 25Mhz. When using
// the env:blackpill_f401ce env, the default HSE_VALUE = 8000000
// should be changed by adding this build flag in platformio.ini:
//
//  -D HSE_VALUE=25000000
//
#if (HSE_VALUE) != 25000000
#error "HSE_VALUE should match crystal clock of 25000000"
#endif

constexpr uint8_t kColor8Blue = 0x3;

// TODO: move the lvgl tick timer to the lv_adapter files.
//
// Doc: https://github.com/stm32duino/wiki/wiki/HardwareTimer-library
HardwareTimer tim2(TIM2);

static Elapsed elapsed_from_last_dump;

static void lvgl_irq_tick() { lv_tick_inc(5); }

void setup() {
  // Init hardware.
  gpio::MX_GPIO_Init();
  i2c::MX_I2C1_Init();
  dma::MX_DMA_Init();
  tim::MX_TIM1_Init();
  adc::MX_ADC1_Init();

  acquisition::Settings settings;
  config_eeprom::read_acquisition_settings(&settings);
  acquisition::setup(settings);

  // Since DMA is in done in 16 bit units (half words), we specify the total
  // count of 16 bit values in buffer1 + buffer2. We cas the buffer point to
  // uint32_t as expected by the API.
  HAL_ADC_Start_DMA(&adc::hadc1, (uint32_t*)dma::kDmaAdcPointBuffer1,
                    dma::kDmaAdcPointBufferSize * 2 * 2);

  // HAL_TIM_PWM_Start(&tim::htim1, TIM_CHANNEL_1);
  HAL_TIM_PWM_Start(&tim::htim1, TIM_CHANNEL_1);

  elapsed_from_last_dump.set(10000);  // force trigger on first loop

  // Start 5ms lvgl interrupts.
  //
  // NOTE: to output the timer pulses for debugging, replace
  // 'NC' with the port name. For example PA15 for LED3 output.
  tim2.setPWM(1, NC, 200, 10, lvgl_irq_tick);

  // TODO: why do we need to init twice for the TFT to work
  // when powering on?  (Not needed for a warm reset.)
  tft_driver::begin();
  tft_driver::fillScreen(kColor8Blue);
  tft_driver::begin();
  tft_driver::fillScreen(kColor8Blue);

  lv_adapter::setup();

  acquisition::reset_state();

  screen_manager::setup();

  lv_task_handler();

  delay(50);  // let the screen process the data.

  TFT_BL_HIGH;
}

void loop() {
  // LVGL processing and rendering.
  lv_task_handler();

  // Screen updates.
  screen_manager::loop();

  // Heartbeat.
  if (millis() % 3000 < 50) {
    LED1_ON;
  } else {
    LED1_OFF;
  }

  //Periodic report over USB/Serial.
  if (elapsed_from_last_dump.elapsed_millis() > 5000) {
    elapsed_from_last_dump.reset();
    Serial.printf("\nMemory: %d\n", memory::free_memory());
    lv_adapter::dump_stats();
  }
}

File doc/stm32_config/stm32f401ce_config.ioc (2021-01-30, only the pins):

Mcu.UserName=STM32F401CEUx
PA0-WKUP.GPIO_Label=TFT_WR
PA0-WKUP.Signal=GPIO_Output
PA1.GPIO_Label=TFT_RST
PA1.Signal=GPIO_Output
PA10.GPIO_Label=TFT_D6
PA10.Signal=GPIO_Output
PA11.Signal=USB_OTG_FS_DM
PA12.Signal=USB_OTG_FS_DP
PA13.Signal=SYS_JTMS-SWDIO
PA14.Signal=SYS_JTCK-SWCLK
PA15.GPIO_Label=TFT_D10               
PA15.Signal=GPIO_Output
PA2.GPIO_Label=TFT_D14
PA2.Signal=GPIO_Output
PA3.GPIO_Label=TFT_D12
PA3.Signal=GPIO_Output
PA4.GPIO_Label=TFT_D11
PA4.Signal=GPIO_Output
PA5.GPIO_Label=TFT_D9
PA5.Signal=GPIO_Output
PA6.GPIO_Label=TFT_D8
PA6.Signal=GPIO_Output
PA7.GPIO_Label=TFT_D7
PA7.Signal=GPIO_Output
PA8.Signal=S_TIM1_CH1
PA9.GPIO_Label=TFT_D5
PA9.Signal=GPIO_Output
PB0.GPIO_Label=AIN0
PB0.Signal=ADCx_IN8
PB1.GPIO_Label=AIN1
PB1.Signal=ADCx_IN9
PB10.GPIO_Label=TFT_D4
PB10.Signal=GPIO_Output
PB12.GPIO_Label=TFT_D0
PB12.Signal=GPIO_Output
PB13.GPIO_Label=TFT_D1
PB13.Signal=GPIO_Output
PB14.GPIO_Label=TFT_D2
PB14.Signal=GPIO_Output
PB15.GPIO_Label=TFT_D3
PB15.Signal=GPIO_Output
PB3.Signal=SYS_JTDO-SWO
PB4.GPIO_Label=TFT_D13
PB4.Signal=GPIO_Output
PB5.GPIO_Label=TFT_D15
PB5.Signal=GPIO_Output
PB6.Signal=I2C1_SCL
PB7.Signal=I2C1_SDA
PB8.GPIO_Label=TFT_DC
PB8.Signal=GPIO_Output
PB9.GPIO_Label=TFT_BL
PB9.Signal=GPIO_Output
PC13-ANTI_TAMP.GPIO_Label=LED1
PC13-ANTI_TAMP.Signal=GPIO_Output
PC14-OSC32_IN.GPIO_Label=LED2
PC14-OSC32_IN.Signal=GPIO_Output
PC15-OSC32_OUT.GPIO_Label=LED3
PC15-OSC32_OUT.Signal=GPIO_Output

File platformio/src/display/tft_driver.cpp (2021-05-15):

#include "tft_driver.h"

#include <Arduino.h>

#include "bssr_tables.h"
#include "hal/gpio.h"

// // Assuming landscape mode per memory access command 0x36.
#define WIDTH 480
#define HEIGHT 320

#define ILI9488_SLPOUT 0x11

#define ILI9488_DISPON 0x29

#define ILI9488_CASET 0x2A
#define ILI9488_PASET 0x2B
#define ILI9488_RAMWR 0x2C
#define ILI9488_RAMRD 0x2E

namespace tft_driver {

// It seems that the CPU has better access to RAM vs Flash. Copying
// the bssr table to ram increase the transfer rate from ~8.5M
// pixels/sec to ~10M pixels/sec, at the cost of 2KB of RAM.
static uint64_t ram_color_bssr_table[256];

// Sending a byte using the 8 LSB bits of the 16 bit
// data path. This is how commands and their arguments
// are sent. Only colors are sent using 16 bits parallel
// transfer.
//
// TFT_WR is high before and after this function.
static inline void send_byte(uint8_t c) {
  // The TFT D15:D0 are divided across port A and port B. We
  // use a lookup table to set those pins to the desired value.
  // The port A bssr mask also resets the WR bit.
  const uint64_t bssr64 = bssr_tables::direct_bssr_table[c];
  // This also set TFT_WR to 0.
  GPIOA->BSRR = (uint32_t)bssr64;
  GPIOB->BSRR = (uint32_t)(bssr64 >> 32);
  TFT_WR_HIGH;
}

// Colors are sent using 16 bit parallel transfers.
static void send_color8(uint8_t color) {
  // The TFT D15:D0 are divided across port A and port B. We
  // use a lookup table to set those pins to the desired value.
  // The port A bssr mask also resets the WR bit.
  const uint64_t bssr64 = ram_color_bssr_table[color];
  // This also set TFT_WR to 0.
  GPIOA->BSRR = (uint32_t)bssr64;
  GPIOB->BSRR = (uint32_t)(bssr64 >> 32);
  TFT_WR_HIGH;
}

void writecommand(uint8_t c) {
  TFT_DC_LOW;  // Indicates a command
  send_byte(c);
}

void writedata(uint8_t c) {
  TFT_DC_HIGH;  // Indicates data
  send_byte(c);
}

void begin() {
  // Cache the BSSR color table in RAM for faster access.
  for (int i = 0; i < 256; i++) {
    ram_color_bssr_table[i] = bssr_tables::color_bssr_table[i];
  }

  // NOTE: we enable TFT_BL (backlight) later in main after completing
  // the initialization and filling the screen.
  TFT_WR_HIGH;
  TFT_RST_HIGH;

  delay(5);
  TFT_RST_LOW;
  delay(20);
  TFT_RST_HIGH;
  delay(150);

  writecommand(0xE0);
  writedata(0x00);
  writedata(0x03);
  writedata(0x09);
  writedata(0x08);
  writedata(0x16);
  writedata(0x0A);
  writedata(0x3F);
  writedata(0x78);
  writedata(0x4C);
  writedata(0x09);
  writedata(0x0A);
  writedata(0x08);
  writedata(0x16);
  writedata(0x1A);
  writedata(0x0F);

  writecommand(0XE1);
  writedata(0x00);
  writedata(0x16);
  writedata(0x19);
  writedata(0x03);
  writedata(0x0F);
  writedata(0x05);
  writedata(0x32);
  writedata(0x45);
  writedata(0x46);
  writedata(0x04);
  writedata(0x0E);
  writedata(0x0D);
  writedata(0x35);
  writedata(0x37);
  writedata(0x0F);

  writecommand(0XC0);  // Power Control 1
  writedata(0x17);     // Vreg1out
  writedata(0x15);     // Verg2out

  writecommand(0xC1);  // Power Control 2
  writedata(0x41);     // VGH,VGL

  writecommand(0xC5);  // Power Control 3
  writedata(0x00);
  writedata(0x12);  // Vcom
  writedata(0x80);

  writecommand(0x36);  // Memory Access
  writedata(0xe8);     // landscape mode. Swappin and mirroring x, y.

  // NOTE: For 16bit parallel transfer, IM jumbers need to be set
  // as 010.
  writecommand(0x3A);  // Interface Pixel Format
  writedata(0x55);     // 16 bit

  writecommand(0XB0);  // Interface Mode Control
  writedata(0x80);     // SDO NOT USE

  writecommand(0xB1);  // Frame rate
  writedata(0xA0);     // 60Hz

  writecommand(0xB4);  // Display Inversion Control
  writedata(0x02);     // 2-dot

  writecommand(0XB6);  // Display Function Control  RGB/MCU Interface Control

  writedata(0x02);  // MCU
  writedata(0x02);  // Source,Gate scan dieection

  writecommand(0XE9);  // Set Image Functio
  writedata(0x00);     // Disable 24 bit data

  writecommand(0xF7);  // Adjust Control
  writedata(0xA9);
  writedata(0x51);
  writedata(0x2C);
  writedata(0x82);  // D7 stream, loose

  writecommand(ILI9488_SLPOUT);  // Exit Sleep
  delay(120);
  writecommand(ILI9488_DISPON);  // Display on
}

// This is followed by a stream of pixels to render in this
// rectangle.
void setAddrWindow(uint16_t x0, uint16_t y0, uint16_t x1, uint16_t y1) {
  writecommand(ILI9488_CASET);  // Column addr set
  writedata(x0 >> 8);
  writedata(x0 & 0xFF);  // XSTART
  writedata(x1 >> 8);
  writedata(x1 & 0xFF);  // XEND

  writecommand(ILI9488_PASET);  // Row addr set
  writedata(y0 >> 8);
  writedata(y0 & 0xff);  // YSTART
  writedata(y1 >> 8);
  writedata(y1 & 0xff);  // YEND

  // Should follow by data bytes.
  writecommand(ILI9488_RAMWR);  // write to RAM

  // Next send the data bytes.
  TFT_DC_HIGH;
}

//  This is used to init the screen.
void fillRect(int16_t x, int16_t y, int16_t w, int16_t h, uint8_t color) {
  // rudimentary clipping (drawChar w/big text requires this)
  if ((x >= WIDTH) || (y >= HEIGHT)) return;
  if ((x + w - 1) >= WIDTH) w = WIDTH - x;
  if ((y + h - 1) >= HEIGHT) h = HEIGHT - y;

  setAddrWindow(x, y, x + w - 1, y + h - 1);

  for (int32_t i = w * h; i > 0; i--) {
    send_color8(color);
  }
}

//  This is used to init the screen.
void fillScreen(uint8_t color) { fillRect(0, 0, WIDTH, HEIGHT, color); }

// NOTE: The value written to GPIOA->BSRR also resets the TFT_WR output.
#define RENDER_NEXT_PIXEL                               \
  {                                                     \
    const uint64_t bssr64 = ram_color_bssr_table[*p++]; \
    GPIOA->BSRR = (uint32_t)bssr64;                     \
    GPIOB->BSRR = (uint32_t)(bssr64 >> 32);             \
    TFT_WR_HIGH;                                        \
  }

// This function is time critical since it dominates the screen update time.
// LVGL writes to the screen via this function.
extern void render_buffer(uint16_t x1, uint16_t y1, uint16_t x2, uint16_t y2,
                          uint8_t* color8_p) {
  setAddrWindow(x1, y1, x2, y2);

  const int32_t w_pixels = x2 - x1 + 1;
  const int32_t h_pixels = y2 - y1 + 1;

  uint8_t* p = color8_p;
  uint32_t pixels_left = w_pixels * h_pixels;

  // The code below was optimized for fast rendering, since it
  // handles all the LVGL display updates.
  //
  // First do inlined chunks of 10 per iteration. This
  // increase the transfer rate from ~5M pixels/sec to
  // ~9M.
  while (pixels_left >= 10) {
    pixels_left -= 10;
    RENDER_NEXT_PIXEL;
    RENDER_NEXT_PIXEL;
    RENDER_NEXT_PIXEL;
    RENDER_NEXT_PIXEL;
    RENDER_NEXT_PIXEL;

    RENDER_NEXT_PIXEL;
    RENDER_NEXT_PIXEL;
    RENDER_NEXT_PIXEL;
    RENDER_NEXT_PIXEL;
    RENDER_NEXT_PIXEL;
  }

  // Do the rest of the pixels, one at a time, up to
  // 9 iterations.
  while (pixels_left > 0) {
    pixels_left--;
    RENDER_NEXT_PIXEL;
  }
}

}  // namespace tft_driver

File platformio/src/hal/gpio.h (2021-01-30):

// Definitions and initialization of the pins used.

#pragma once

#include "stm32f4xx_hal.h"

// NOTE: LED1, LED2 are on the 32khz crystal pins but we
// don't run that oscilator and it seems to work.

// Pin assignments below copied from MxCube generated configuration.

#define LED1_Pin GPIO_PIN_13
#define LED1_GPIO_Port GPIOC
#define LED2_Pin GPIO_PIN_14
#define LED2_GPIO_Port GPIOC
#define LED3_Pin GPIO_PIN_15
#define LED3_GPIO_Port GPIOC
#define TFT_WR_Pin GPIO_PIN_0
#define TFT_WR_GPIO_Port GPIOA
#define TFT_RST_Pin GPIO_PIN_1
#define TFT_RST_GPIO_Port GPIOA
#define TFT_D14_Pin GPIO_PIN_2
#define TFT_D14_GPIO_Port GPIOA
#define TFT_D12_Pin GPIO_PIN_3
#define TFT_D12_GPIO_Port GPIOA
#define TFT_D11_Pin GPIO_PIN_4
#define TFT_D11_GPIO_Port GPIOA
#define TFT_D9_Pin GPIO_PIN_5
#define TFT_D9_GPIO_Port GPIOA
#define TFT_D8_Pin GPIO_PIN_6
#define TFT_D8_GPIO_Port GPIOA
#define TFT_D7_Pin GPIO_PIN_7
#define TFT_D7_GPIO_Port GPIOA
#define AIN0_Pin GPIO_PIN_0
#define AIN0_GPIO_Port GPIOB
#define AIN1_Pin GPIO_PIN_1
#define AIN1_GPIO_Port GPIOB
#define TFT_D4_Pin GPIO_PIN_10
#define TFT_D4_GPIO_Port GPIOB
#define TFT_D0_Pin GPIO_PIN_12
#define TFT_D0_GPIO_Port GPIOB
#define TFT_D1_Pin GPIO_PIN_13
#define TFT_D1_GPIO_Port GPIOB
#define TFT_D2_Pin GPIO_PIN_14
#define TFT_D2_GPIO_Port GPIOB
#define TFT_D3_Pin GPIO_PIN_15
#define TFT_D3_GPIO_Port GPIOB
#define TFT_D5_Pin GPIO_PIN_9
#define TFT_D5_GPIO_Port GPIOA
#define TFT_D6_Pin GPIO_PIN_10
#define TFT_D6_GPIO_Port GPIOA
#define TFT_D10_Pin GPIO_PIN_15
#define TFT_D10_GPIO_Port GPIOA
#define TFT_D13_Pin GPIO_PIN_4
#define TFT_D13_GPIO_Port GPIOB
#define TFT_D15_Pin GPIO_PIN_5
#define TFT_D15_GPIO_Port GPIOB
#define TFT_DC_Pin GPIO_PIN_8
#define TFT_DC_GPIO_Port GPIOB
#define TFT_BL_Pin GPIO_PIN_9
#define TFT_BL_GPIO_Port GPIOB


namespace gpio {
  
// Call this once during initialization.
void MX_GPIO_Init();
}  // namespace gpio.


// Fast controls for LED0 output. ACTIVE LOW.

// Fast controls for LED1 output.
#define LED1_ON \
  { LED1_GPIO_Port->BSRR = LED1_Pin; }
#define LED1_OFF \
  { LED1_GPIO_Port->BSRR = (uint32_t)LED1_Pin << 16u; }

// Fast controls for LED2 output.
#define LED2_ON \
  { LED2_GPIO_Port->BSRR = LED2_Pin; }
#define LED2_OFF \
  { LED2_GPIO_Port->BSRR = (uint32_t)LED2_Pin << 16u; }

  // Fast controls for LED2 output.
#define LED3_ON \
  { LED3_GPIO_Port->BSRR = LED3_Pin; }
#define LED3_OFF \
  { LED3_GPIO_Port->BSRR = (uint32_t)LED3_Pin << 16u; }

// Fast controls for TFT_DC output.
#define TFT_DC_HIGH \
  { TFT_DC_GPIO_Port->BSRR = TFT_DC_Pin; }
#define TFT_DC_LOW \
  { TFT_DC_GPIO_Port->BSRR = (uint32_t)TFT_DC_Pin << 16u; }

// Fast controls for TFT_WR output.
#define TFT_WR_HIGH \
  { TFT_WR_GPIO_Port->BSRR = TFT_WR_Pin; }
#define TFT_WR_LOW \
  { TFT_WR_GPIO_Port->BSRR = (uint32_t)TFT_WR_Pin << 16u; }

  // Fast controls for TFT_NRST output.
#define TFT_RST_HIGH \
  { TFT_RST_GPIO_Port->BSRR = TFT_RST_Pin; }
#define TFT_RST_LOW \
  { TFT_RST_GPIO_Port->BSRR = (uint32_t)TFT_RST_Pin << 16u; }

  // Fast controls for TFT_BL output.
#define TFT_BL_HIGH \
  { TFT_BL_GPIO_Port->BSRR = TFT_BL_Pin; }
#define TFT_BL_LOW \
  { TFT_BL_GPIO_Port->BSRR = (uint32_t)TFT_BL_Pin << 16u; }

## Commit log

2021-01-30 Created repository
    [ER-TFT035-6.step, stepper_analyzer.kicad_pcb, stepper_analyzer.sch]
2021-01-30 Added board images
2021-01-30 Updated documentation
    [base.step, base.stl]
2021-01-30 Updated 3D model
    [base.stl]
2021-01-31 Reduce annoyance from blinking LED3 and added a dated binary release.
2021-02-02 Added analysis of fractional steps.
    [quadrants.ods]
2021-02-27 Extended the click area of buttons.
2021-03-27 Assorted tweaks.
    [base.step, case.stl]
2021-04-16 added the enclosed case option
2021-04-17 Added BOM.
    [BOM.csv, BOM.xlsx]
2021-04-17 Removed the DO NOT POPULATE comment for the 10uf caps since they are populated in the prototype.
    [stepper_analyzer.sch]
2021-04-18 Added 0.3 membrane at the back cover holes to improve 3d printing without material support. Should be drilled through with a 2.5mm (aprox 3/32" imperial).
    [case.stl]
2021-04-20 Updated BOM link.
2021-05-14 arduino camel case fix
    [tft_driver.cpp, touch_driver.cpp]
2021-05-16 Added an errata regarding floating TFT pin 26.
    [stepper_analyzer.sch]
2021-05-16 Updated schematic with errata

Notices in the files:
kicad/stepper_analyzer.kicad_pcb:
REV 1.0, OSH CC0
